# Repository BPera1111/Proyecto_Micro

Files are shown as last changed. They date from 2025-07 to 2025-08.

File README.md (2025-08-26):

# 🔧 CNC Láser Controller - STM32F103C8T6

Proyecto de conversión de impresora 3D a CNC láser utilizando microcontrolador STM32F103C8T6 (Blue Pill).

## 📋 Características

- **Control de 3 ejes** (X, Y, Z) con motores paso a paso
- **Comunicación USB CDC** para comandos G-code
- **Finales de carrera** en los 3 ejes
- **LEDs indicadores** de dirección de movimiento
- **Procesamiento G-code básico** (G0, G1)

## 🔧 Hardware Requerido

- **STM32F103C8T6** (Blue Pill)
- **ST-Link V2** (para programación y debug)
- **3x Drivers de motores paso a paso** (A4988/DRV8825)
- **3x Motores paso a paso NEMA17**
- **3x Finales de carrera** (endstops)
- **2x LEDs** (indicadores de dirección)

## 📍 Configuración de Pines

| Función | Pin STM32 | Descripción |
|---|---|---|
| **Motor X** | | |
| X_STEP | PB6 | Pulsos de paso |
| X_DIR | PB7 | Dirección |
| X_EN | PB8 | Habilitación |
| X_MIN | PB12 | Final de carrera |
| **Motor Y** | | |
| Y_STEP | PB9 | Pulsos de paso |
| Y_DIR | PB3 | Dirección |
| Y_EN | PB4 | Habilitación |
| Y_MIN | PB13 | Final de carrera |
| **Motor Z** | | |
| Z_STEP | PA8 | Pulsos de paso |
| Z_DIR | PA9 | Dirección |
| Z_EN | PA10 | Habilitación |
| Z_MIN | PB14 | Final de carrera |
| **LEDs** | | |
| LED_HORARIO | PB0 | Indicador sentido horario |
| LED_ANTIHORARIO | PB1 | Indicador sentido antihorario |

## 🚀 Instalación y Configuración

### 1. Preparación del entorno

```bash
# Instalar pyOCD para programación
pip install pyocd

# Verificar dispositivos conectados
pyocd list
```

### 2. Programación del firmware

```bash
# Navegar al directorio Debug generado por STM32CubeIDE
cd Proyecto_Micro/CNC/Debug

# Flashear el firmware (borra chip completo)
pyocd flash --target stm32f103rc --erase=chip CNC.elf
```

## 🐛 Debug y Desarrollo

### Configuración para VSCode

1. **Instalar extensión:** `Cortex-Debug` en VSCode

2. **Crear archivo de configuración:** `.vscode/launch.json`

```json
{
  "version": "0.2.0",
  "configurations": [
    {
      "name": "Debug STM32F103 via pyOCD",
      "type": "cortex-debug",
      "request": "launch",
      "executable": "${workspaceFolder}/CNC/Debug/CNC.elf",
      "servertype": "external",
      "gdbPath": "C:/ST/STM32CubeIDE_1.19.0/STM32CubeIDE/plugins/com.st.stm32cube.ide.mcu.externaltools.gnu-tools-for-stm32.13.3.rel1.win32_1.0.0.202411081344/tools/bin/arm-none-eabi-gdb.exe",
      "armToolchainPath": "C:/ST/STM32CubeIDE_1.19.0/STM32CubeIDE/plugins/com.st.stm32cube.ide.mcu.externaltools.gnu-tools-for-stm32.13.3.rel1.win32_1.0.0.202411081344/tools/bin",
      "gdbTarget": "localhost:3333",
      "runToEntryPoint": "main",
      "device": "STM32F103C8"
    }
  ]
}
```

3. **Iniciar servidor GDB:**

```bash
# En terminal separado
pyocd gdbserver --target stm32f103rc
```

4. **Debuggear:** Usar el menú de depuración de VSCode seleccionando la configuración "Debug STM32F103 via pyOCD"

## 🎮 Comandos G-code Soportados

| Comando | Descripción | Ejemplo |
|---|---|---|
| `G0 Xnn Ynn Znn` | Movimiento rápido | `G0 X100 Y50` |
| `G1 Xnn Ynn Znn` | Movimiento lineal | `G1 X50 Y25 Z10` |

### Ejemplos de uso:

```gcode
G1 X100        # Mover X a 100mm
G1 Y50         # Mover Y a 50mm
G1 X50 Y25     # Movimiento combinado XY
G1 X0 Y0 Z0    # Volver al origen
```

## ⚙️ Configuración del Sistema

- **Velocidad de pasos:** 800μs entre pasos
- **Resolución:** 2000 pasos/revolución
- **Frecuencia de loop:** 20Hz (cada 50ms)
- **Verificación endstops:** Cada 10ms
- **Comunicación:** USB CDC (puerto serie virtual)

## 🛠️ Desarrollo

### Estructura del proyecto:

```
Proyecto_Micro/
├── README.md
├── AnteProyecto/          # Documentación LaTeX
└── CNC/                   # Proyecto STM32CubeIDE
    ├── Core/
    │   ├── Inc/           # Headers
    │   └── Src/           # Código fuente
    ├── Drivers/           # HAL STM32
    ├── USB_DEVICE/        # Configuración USB CDC
    └── Debug/             # Archivos compilados
```

### Control de debug:

En `main.c`, línea 44:
```c
#define DEBUG_MESSAGES 1  // 1=activar, 0=desactivar mensajes debug
```

## 📝 Notas

- **Ajustar rutas:** Modificar las rutas en `launch.json` según tu instalación de STM32CubeIDE
- **Target device:** Verificar que el target `stm32f103rc` sea compatible con tu Blue Pill
- **Conexiones:** Asegurar conexiones correctas de ST-Link y USB CDC

## 🔮 Próximas funcionalidades

- [ ] Control de láser con PWM
- [ ] Comandos M3/M5 (encender/apagar láser)
- [ ] Interpolación lineal simultánea
- [ ] Homing automático
- [ ] Control de velocidad variable
- [ ] Sistema de coordenadas robusto
- [ ] UART con ESP32

---

**Autores:** BPera1111 y lautoping  
**Fecha:** Julio 2025

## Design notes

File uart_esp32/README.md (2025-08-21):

# ESP32 UART Bridge para CNC Monitor

Este proyecto convierte un ESP32 en un puente UART/WiFi para monitorear tu CNC STM32 sin necesidad de cable USB-TTL.

## 🔧 Hardware Necesario

- ESP32 (cualquier modelo con WiFi)
- Cables jumper para conexiones
- Protoboard (opcional pero recomendado)

## 📋 Conexiones

```
ESP32          STM32 (CNC)
GPIO16 (RX2) ←→ TX (PA9 o según tu configuración)
GPIO17 (TX2) ←→ RX (PA10 o según tu configuración)  
GND          ←→ GND (¡MUY IMPORTANTE!)
```

**⚠️ IMPORTANTE:**
- NO conectes VCC del ESP32 al STM32 si ambos tienen alimentación independiente
- Asegúrate de conectar las tierras (GND) entre ambos dispositivos
- Verifica que los niveles de voltaje sean compatibles (ambos trabajan a 3.3V)

## 🚀 Instalación del Software

### 1. Preparar Arduino IDE

1. Instala Arduino IDE (versión 1.8.19 o superior)
2. Agrega el soporte para ESP32:
   - Ve a `Archivo > Preferencias`
   - En "URLs adicionales de gestor de tarjetas" agrega:
     ```
     https://dl.espressif.com/dl/package_esp32_index.json
     ```
   - Ve a `Herramientas > Placa > Gestor de tarjetas`
   - Busca "ESP32" e instala "ESP32 by Espressif Systems"

### 2. Instalar Librerías Necesarias

Ve a `Herramientas > Administrar bibliotecas` e instala:

- **WebSockets** by Markus Sattler (versión 2.3.6 o superior)
  ```
  Buscar: "WebSockets Markus"
  ```

### 3. Configurar el Código

1. Abre `uart_bridge.ino` en Arduino IDE
2. **MODIFICA estas líneas con tu configuración WiFi:**
   ```cpp
   const char* ssid = "TU_RED_WIFI";        // ← Cambia por tu red WiFi
   const char* password = "TU_PASSWORD";    // ← Cambia por tu contraseña
   ```

3. **Verifica la configuración UART:**
   ```cpp
   #define STM32_UART_BAUD 115200  // Velocidad igual que tu STM32
   #define STM32_RX_PIN 16         // Pin RX del ESP32
   #define STM32_TX_PIN 17         // Pin TX del ESP32
   ```

### 4. Subir el Código

1. Conecta tu ESP32 por USB
2. Selecciona la placa correcta en `Herramientas > Placa`
3. Selecciona el puerto COM correcto
4. Haz clic en "Subir" (flecha hacia la derecha)

## 📱 Uso del Sistema

### 1. Primera Configuración

1. Después de subir el código, abre el Monitor Serie (115200 baud)
2. Reinicia el ESP32 y verás algo como:
   ```
   === ESP32 CNC UART Bridge ===
   Conectando a WiFi....
   WiFi conectado!
   IP: 192.168.1.100
   Sistema listo!
   ```

### 2. Acceso Web

1. Abre tu navegador web
2. Ve a la IP que mostró el ESP32 (ej: `http://192.168.1.100`)
3. Verás la interfaz web del monitor CNC

### 3. Funciones Disponibles

- **Monitor en tiempo real:** Ver todos los mensajes del STM32
- **Envío de comandos:** Escribir G-code y enviarlo al CNC
- **Comandos rápidos:** Botones para comandos comunes (Home, Status, etc.)
- **Interfaz responsive:** Funciona en PC, tablet y móvil

## 🎮 Comandos de Prueba

Una vez conectado, prueba estos comandos básicos:

```gcode
G28          ; Home (ir a origen)
M114         ; Reportar posición actual  
G1 X10 Y10   ; Mover a posición X10, Y10
M105         ; Estado del sistema
G21          ; Modo milímetros
G90          ; Modo coordenadas absolutas
```

## 🔍 Resolución de Problemas

### No conecta a WiFi
- Verifica SSID y contraseña
- Asegúrate que el ESP32 esté cerca del router
- Revisa el Monitor Serie para ver errores

### No recibe datos del STM32
- Verifica las conexiones TX/RX (pueden estar cruzadas)
- Confirma que las velocidades UART coincidan
- Asegúrate que GND esté conectado

### Página web no carga
- Verifica la IP en el Monitor Serie
- Asegúrate que tu PC esté en la misma red WiFi
- Prueba reiniciar el ESP32

### Comandos no llegan al STM32
- Revisa las conexiones físicas
- Confirma que el STM32 esté configurado para UART
- Verifica la velocidad de baudios

## 📊 Ventajas de esta Solución

✅ **Sin cables USB:** Monitoreo inalámbrico  
✅ **Interfaz web:** No necesitas software especial  
✅ **Multiplataforma:** Funciona en PC, móvil, tablet  
✅ **Tiempo real:** Comunicación bidireccional instantánea  
✅ **Comandos rápidos:** Botones para operaciones comunes  
✅ **Historial:** Ve todo el log de comunicación  
✅ **Portable:** Accede desde cualquier dispositivo en la red  

## 🔄 Actualizaciones

Para modificar el código:
1. Edita `uart_bridge.ino`
2. Vuelve a subir al ESP32
3. El ESP32 mantendrá la nueva configuración

## 🤝 Soporte

Si tienes problemas:
1. Revisa las conexiones físicas
2. Verifica la configuración WiFi
3. Consulta el Monitor Serie para errores
4. Prueba con comandos simples primero

¡Disfruta tu monitor CNC inalámbrico! 🎉

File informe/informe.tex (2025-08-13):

\documentclass[12pt]{article}
\usepackage[spanish]{babel}
\usepackage[utf8]{inputenc}
\usepackage{graphicx}
\usepackage{amsmath}
\usepackage{xcolor}
\usepackage{tikz}
\usetikzlibrary{arrows.meta, positioning, shapes}
\usepackage{url}
\usepackage{hyperref}
\usepackage{amssymb} % For \checkmark symbol
\hypersetup{
    colorlinks=true,
    linkcolor=black,
    citecolor=black,
    urlcolor=black,
    pdfborder={0 0 0}
}
\usepackage{geometry}
\usepackage{fancyhdr}
\usepackage{lastpage}
\usepackage{listings}
\usepackage{float}
\usepackage{longtable}
\usepackage{multirow}
\geometry{a4paper, margin=1.3cm}

\title{Anteproyecto: Impresora 3D Modificada para Grabado Láser CNC de PCB}
\author{Nombre del estudiante}
\date{\today}

% Configuración de encabezados y pies de página
\pagestyle{fancy}
\fancyhf{} % Limpia encabezados y pies de página

% Encabezado
\fancyhead[L]{\scriptsize UNCuyo - Ing. Mecatrónica\\Mendoza - Argentina}
\fancyhead[C]{\scriptsize\textbf{\textbf{Microcontroladores y Electrónica de Potencia (Año 2024)}\\
\textbf{PROYECTO GLOBAL INTEGRADOR}}}
\fancyhead[R]{\scriptsize Peña Lautaro, Peralta Bruno\\19/07/2025}

% Pie de página
\fancyfoot[C]{Pág. \thepage\ de \pageref{LastPage}}

\setlength{\headheight}{16.9528pt}  % importante si usás fancyhdr con varios renglones
\setlength{\headsep}{0.5cm}    % separación entre cabecera y texto

% \fancyhead[L]{Automática y Máquinas Eléctricas} % Encabezado izquierdo
% \fancyhead[C]{2025} % Encabezado central
% \fancyhead[R]{Peña Lautaro, Peralta Bruno} % Encabezado derecho
% \fancyfoot[C]{\thepage} % Número de página centrado en el pie de página

% Configuración de código
\lstset{
    backgroundcolor=\color{gray!10},
    basicstyle=\ttfamily\footnotesize,
    breaklines=true,
    captionpos=b,
    commentstyle=\color{green!40!black},
    escapeinside={\%*}{*},
    frame=single,
    keywordstyle=\color{blue},
    numbers=left,
    numbersep=5pt,
    numberstyle=\tiny\color{gray},
    rulecolor=\color{black},
    showspaces=false,
    showstringspaces=false,
    stringstyle=\color{orange},
    tabsize=4
}

\begin{document}

% Portada
\begin{titlepage}
    \centering

    % Logo
    \par\vspace{1cm}
    \vspace{2cm}
    % Título
    {\Huge \textbf{Proyecto Global Integrador:}\\[0.5cm]
    \textbf{CNC Laser de 3 Ejes}\vspace{2cm}}
    % \textbf{Motor Sincrónico de Imanes Permanentes}\par}\vspace{2cm}
    
    % Autores
    {\Large Peña Lautaro - 13099\\
    Peralta Bruno - 13220\par}\vspace{0.5cm}
    
    % Profesor titular
    {Año 2024\par}
\end{titlepage}

\newpage

% Índice
\tableofcontents
\newpage

% Introducción
\section{Introducción}

El presente proyecto consiste en la modificación de una impresora 3D antigua con el fin de reutilizar su estructura y componentes para desarrollar una máquina CNC de grabado láser destinada a la creación rápida de placas de circuito impreso (PCB). Esta herramienta permitirá fabricar prototipos de forma ágil para proyectos de electrónica y robótica.

La motivación principal radica en el desafío de aprovechar un equipo en desuso y otorgarle una nueva funcionalidad, aportando una solución económica y eficiente para la etapa de prototipado de circuitos. El sistema combina conocimientos de control de motores, programación de microcontroladores, comunicación serial y ejecución de comandos G-code.

\section{Esquema Tecnológico}

\begin{center}
\begin{tikzpicture}[node distance=3cm, auto]
  % Bloques principales
  \node[draw, rectangle, rounded corners, fill=blue!10] (pc) {PC con G-code};
  \node[draw, rectangle, rounded corners, fill=green!10, below of=pc, yshift=-0.5cm] (bluepill) {Blue Pill STM32F103C8T6};
  \node[draw, rectangle, rounded corners, fill=yellow!20, below of=bluepill, yshift=-0.5cm] (ramp) {RAMPS 1.4};
  \node[draw, rectangle, rounded corners, fill=orange!10, below of=ramp, xshift=-5.5cm, yshift=-0.5cm] (driverX) {Driver A4988 - Eje X};
  \node[draw, rectangle, rounded corners, fill=orange!10, below of=ramp, xshift=0cm, yshift=-0.5cm] (driverY) {Driver A4988 - Eje Y};
  \node[draw, rectangle, rounded corners, fill=orange!10, below of=ramp, xshift=5.5cm, yshift=-0.5cm] (driverZ) {Driver A4988 - Eje Z};
  \node[draw, rectangle, rounded corners, fill=red!10, below of=driverX, yshift=-0.5cm] (motorX) {M.PAP NEMA 17HS3430};
  \node[draw, rectangle, rounded corners, fill=red!10, below of=driverY, yshift=-0.5cm] (motorY) {M.PAP NEMA 17HS8401};
  \node[draw, rectangle, rounded corners, fill=red!10, below of=driverZ, yshift=-0.5cm] (motorZ) {M.PAP NEMA 17HS8401};
  \node[draw, rectangle, rounded corners, fill=gray!20, right of=pc, xshift=5cm] (serial) {Monitor Serial};
  \node[draw, rectangle, rounded corners, fill=cyan!20, right of=ramp, xshift=6cm] (endstops) {Fines de carrera};

  % Conexiones
  \draw[-{Stealth}] (pc) -- (bluepill) node[midway, left] {USB Serial};
  \draw[-{Stealth}] (bluepill) -- (ramp) node[midway, left] {Interfaz};
  \draw[-{Stealth}] (ramp) -- (driverX);
  \draw[-{Stealth}] (ramp) -- (driverY);
  \draw[-{Stealth}] (ramp) -- (driverZ);
  \draw[-{Stealth}] (driverX) -- (motorX);
  \draw[-{Stealth}] (driverY) -- (motorY);
  \draw[-{Stealth}] (driverZ) -- (motorZ);
  \draw[-{Stealth}, dashed] (ramp) -- (endstops) node[midway, above] {Sensores};
  \draw[-{Stealth}, dashed] (pc) -- (serial);
\end{tikzpicture}
\end{center}

\section{Detalle de Módulos}

\subsection{Microcontrolador: Blue Pill STM32F103C8T6}
Microcontrolador de 32 bits basado en ARM Cortex-M3, con 72 MHz, 64KB Flash y 20KB RAM. Opera a 3.3V, pero varios pines son tolerantes a 5V. Se programa mediante STM32CubeIDE. Más información en referencia \hyperref[ref1]{[1]}.

\subsection{Drivers A4988}
Módulos controladores de motores paso a paso, permiten controlar corriente y micropasos. Son compatibles con motores NEMA y reciben señales STEP/DIR desde el microcontrolador. Referencia \hyperref[ref2]{[2]}.

\subsection{Motores paso a paso}
\begin{itemize}
  \item \textbf{17HS3430}: torque nominal 26 Ncm, corriente 1.2A/fase, 1.8° por paso. Ideal para eje X.
  \item \textbf{17HS8401}: torque 52 Ncm, corriente 1.8A/fase. Usados en ejes Y y Z.
\end{itemize}
Hojas de datos disponibles en referencias \hyperref[ref3]{[3]} y \hyperref[ref4]{[4]}.

\subsection{RAMPS 1.4}
Placa de expansión diseñada para impresoras 3D, permite conectar drivers A4988, motores, finales de carrera y fuentes de alimentación. Es compatible eléctricamente con el Arduino Mega, pero se adapta a la Blue Pill mediante cableado personalizado. Referencia \hyperref[ref5]{[5]}.

\subsection{Fines de carrera mecánicos}
Interruptores tipo “normalmente cerrados” (NC) conectados a los pines PA12, PA15 y PA11 del microcontrolador. Se usan para detectar los límites de cada eje y realizar homing.

% Funcionamiento general
\section{Funcionamiento general}
\subsection*{Interacción entre módulos y funciones}

\begin{itemize}
    \item \textbf{PC con G-code:} Envía comandos G-code a través de USB Serial. Puede utilizar un monitor serial para control manual y monitoreo.
    \item \textbf{Blue Pill STM32F103C8T6:} Actúa como controlador principal, interpreta los comandos G-code, genera señales de paso y dirección para los motores, y procesa la información de los sensores de fin de carrera.
    \item \textbf{RAMPS 1.4:} Placa de interfaz que conecta el microcontrolador con los drivers de motores y los sensores de límite.
    \item \textbf{Drivers A4988:} Uno por cada eje (X, Y, Z), reciben señales STEP/DIR y controlan la corriente y microstepping de los motores.
    \item \textbf{Motores paso a paso NEMA:} Ejecutan el movimiento mecánico.
    \item \textbf{Sensores de fin de carrera:} Detectan la posición de referencia (\textit{home}) y evitan movimientos fuera del rango mecánico.
\end{itemize}

\subsection*{Diagrama de flujo}

% Diagrama de flujo del funcionamiento general
\begin{center}
\begin{tikzpicture}[
    scale=0.7,
    transform shape,
    node distance=1.5cm,
    every node/.style={font=\scriptsize},
    process/.style={rectangle, draw, fill=blue!10, rounded corners, minimum width=2.2cm, minimum height=0.7cm, align=center},
    decision/.style={draw, shape=diamond, fill=yellow!20, inner sep=0.15cm, align=center},
    startstop/.style={rectangle, draw, fill=green!20, rounded corners, minimum width=2.2cm, minimum height=0.7cm, align=center},
    arrow/.style={-Stealth, thick}
]

% Nodos
\node[startstop] (start) {Inicio sistema};
\node[process, below of=start] (init) {Inicializar módulos};
\node[process, below of=init] (recv) {Recibir G-code desde PC};
\node[process, below of=recv] (interp) {Interpretar comando};
\node[decision, below of=interp, yshift=-2cm] (decision1) {¿Es comando de movimiento?};
\node[process, right=4.5cm of decision1] (action) {Ejecutar acción\\(ej: encender láser)};
\node[process, below=1cm of decision1] (calc) {Calcular trayectoria\\y pasos de motores};
\node[process, below of=calc] (send) {Enviar señales a drivers};
\node[process, below of=send] (read) {Leer sensores de límites};
\node[decision, below of=read, yshift=-2cm] (decision2) {¿Fin de carrera activado?};
\node[process, left=4.5cm of decision2] (stopm) {Detener movimiento};
\node[process, below=1cm of decision2] (wait) {Esperar nuevo comando};
\node[startstop, below=1cm of stopm] (error) {Error};

% Flechas
\draw[arrow] (start) -- (init);
\draw[arrow] (init) -- (recv);
\draw[arrow] (recv) -- (interp);
\draw[arrow] (interp) -- (decision1);
\draw[arrow] (decision1.east) -- node[above]{No} (action.west);
\draw[arrow] (decision1.south) -- node[left]{Sí} (calc.north);
\draw[arrow] (action.south) |- (wait.east);
\draw[arrow] (calc) -- (send);
\draw[arrow] (send) -- (read);
\draw[arrow] (read) -- (decision2);
\draw[arrow] (decision2.west) -- node[above]{Sí} (stopm.east);
\draw[arrow] (decision2.south) -- node[left]{No} (wait.north);
\draw[arrow] (stopm.south) -- (error.north);
\draw[arrow] (wait.west) -- ++(-9,0) |- (interp.west);

\end{tikzpicture}
\end{center}

% \end{tikzpicture}

% Programación
\section{Programación}

\subsection{Configuración de Periféricos del Controlador STM32F103C8T6}

\subsubsection{Interfaces de Comunicación}

\textbf{USB CDC (Communication Device Class):} el sistema utiliza comunicación USB para interactuar con el software de control externo (software host), implementando un puerto serial virtual.

\begin{itemize}
    \item \textbf{Pines:} PA11 (USB\_DM), PA12 (USB\_DP)
    \item \textbf{Funcionalidad:} Comunicación serie virtual via USB
    \item \textbf{Buffer:} RX=1024 bytes, TX=1024 bytes
    \item \textbf{Sistema de Cola:} Implementado para transmisión confiable
    \item \textbf{Interrupción:} \texttt{USB\_LP\_CAN1\_RX0\_IRQn} habilitada
\end{itemize}

\subsubsection{Control de Motores Paso a Paso}

\textbf{Configuración GPIO para Motores:} el sistema controla 3 motores paso a paso (ejes X, Y, Z) mediante pines GPIO configurados como salidas push-pull:

\begin{table}[h]
\centering
\begin{tabular}{|l|c|c|c|c|}
\hline
\textbf{Eje} & \textbf{STEP} & \textbf{DIR} & \textbf{EN} & \textbf{Endstop} \\
\hline
X & PB6 & PB7 & PA8 & PB12 \\
Y & PB9 & PB3 & PB4 & PB13 \\
Z & PA8 & PA9 & PA10 & PB14 \\
\hline
\end{tabular}
\caption{Configuración de pines para control de motores}
\end{table}

\textbf{Características de Timing:}
\begin{itemize}
    \item \textbf{Delay base entre pasos}: 800 µs (configurable)
    \item \textbf{Pulso de STEP}: 2 µs de duración mínima
    \item \textbf{Velocidad máxima}: Limitada por \texttt{calculateStepDelay()} basado en feed rate
    \item \textbf{Timing preciso}: Utilización del contador DWT para delays de microsegundos
\end{itemize}

\subsubsection{Sistema de Interrupciones Externas}

\textbf{Finales de Carrera:} configuración de interrupciones para detección de límites físicos:

\begin{itemize}
    \item \textbf{Pines}: PB12, PB13, PB14
    \item \textbf{Modo}: Interrupción por flanco ascendente
    \item \textbf{Pull-up}: Resistencias pull-up internas habilitadas
    \item \textbf{Prioridad}: Prioridad 0 (máxima) para respuesta inmediata
    \item \textbf{Debounce}: Implementado por software (50ms)
\end{itemize}

\subsubsection{Indicadores LED}

\textbf{LEDs de Estado}
\begin{itemize}
    \item \textbf{LED\_CHECK} (PB1): Indicador de sistema activo
    \item \textbf{LED\_ERROR} (PB0): Indicador de errores del sistema
    \item \textbf{Configuración}: Salidas push-pull, activo en alto
\end{itemize}

\subsubsection{Configuración del Sistema de Reloj}

\begin{itemize}
    \item \textbf{Oscilador Externo (HSE):} 8 MHz con PLL x6 = 48 MHz de frecuencia del sistema
    \item \textbf{AHB Clock:} 48 MHz
    \item \textbf{APB1 Clock:} 24 MHz (dividido por 2)
    \item \textbf{APB2 Clock:} 48 MHz
    \item \textbf{USB Clock:} Derivado del PLL para operación a 48 MHz
\end{itemize}

\subsection{Módulos Externos}

\subsubsection{Drivers de Motores Paso a Paso}
\begin{itemize}
    \item \textbf{Tipo:} Compatibles con señales STEP/DIR/ENABLE
    \item \textbf{Control:} Lógica activa alta para STEP y DIR
    \item \textbf{Enable:} Lógica activa baja (LOW = habilitado)
    \item \textbf{Timing:} Delay de 800 \textmu{}s entre pulsos configurables
\end{itemize}

\subsubsection{Finales de Carrera}
\begin{itemize}
    \item \textbf{Tipo:} Switches normalmente abiertos
    \item \textbf{Conexión:} Con pull-up interno del STM32
    \item \textbf{Detección:} Nivel bajo indica activación
    \item \textbf{Funcionalidad:} Homing y detección de límites
\end{itemize}

\subsection{Descripción de Funciones Codificadas}

\subsubsection{Función main()}

\paragraph{Estructura Principal}
La función \texttt{main()} implementa la inicialización del sistema y el bucle principal:

\begin{itemize}
    \item \textbf{Inicialización HAL}: \texttt{HAL\_Init()}
    \item \textbf{Configuración de reloj}: \texttt{SystemClock\_Config()}
    \item \textbf{Inicialización de periféricos}: GPIO, UART, USB
    \item \textbf{Setup personalizado}: Configuración específica del CNC
    \item \textbf{Bucle infinito}: Procesamiento continuo de comandos y estados
\end{itemize}

\subsubsection{Algoritmos de Control de Movimiento}

\textbf{Algoritmo de Bresenham Modificado:} implementado en \texttt{motion.c} para movimientos lineales coordenados.

\begin{enumerate}
    \item Cálculo de diferencias absolutas entre coordenadas
    \item Determinación del eje dominante (mayor distancia)
    \item Interpolación lineal para mantener proporcionalidad
    \item Control de timing basado en feed rate especificado
\end{enumerate}

\textbf{Generación de Arcos:} Algoritmo para movimientos circulares (G2/G3).

\begin{itemize}
    \item \textbf{Segmentación}: División del arco en 50 segmentos lineales
    \item \textbf{Cálculo trigonométrico}: Uso de seno y coseno para interpolación
    \item \textbf{Precisión}: Balance entre suavidad y carga computacional
\end{itemize}

\subsubsection{Parser G-code}

\textbf{Análisis Léxico y Sintáctico:} implementado en \texttt{gcode\_parser.c} con las siguientes características.

\begin{itemize}
    \item \textbf{Parsing modular}: Separación de análisis y ejecución
    \item \textbf{Validación de grupos modales}: Verificación de compatibilidad de comandos
    \item \textbf{Gestión de estado}: Mantenimiento de estado modal persistente
    \item \textbf{Verificación de límites}: Control de límites software en tiempo real
\end{itemize}

\textbf{Comandos Soportados:}
\begin{itemize}
    \item \textbf{G0}: Movimiento rápido (rapid positioning)
    \item \textbf{G1}: Movimiento lineal con feed rate
    \item \textbf{G2/G3}: Movimientos circulares horario/antihorario
    \item \textbf{G28}: Homing de todos los ejes
    \item \textbf{M114}: Reporte de posición actual
    \item \textbf{M119}: Estado de finales de carrera
    \item \textbf{M503}: Mostrar configuración del sistema
\end{itemize}

\subsubsection{Sistema de Interrupciones}

\textbf{Manejo de Finales de Carrera:} función \texttt{HAL\_GPIO\_EXTI\_Callback()}.

\begin{enumerate}
    \item Identificación del pin que generó la interrupción
    \item Implementación de debounce por software (50ms)
    \item Parada inmediata del movimiento en curso
    \item Generación de mensaje de error específico por eje
    \item Activación del LED de error
\end{enumerate}

\textbf{Interrupción del Sistema (SysTick):}
\begin{itemize}
    \item \textbf{Frecuencia}: 1ms (1kHz)
    \item \textbf{Funcionalidad}: Base de tiempo para \texttt{HAL\_GetTick()}
    \item \textbf{Uso}: Timeouts, delays no bloqueantes
\end{itemize}

\subsubsection{Algoritmo de Homing}

\textbf{Secuencia de Homing Automático:} implementado en \texttt{performHoming()}.

\begin{enumerate}
    \item \textbf{Fase 1}: Movimiento rápido hacia finales de carrera
    \item \textbf{Fase 2}: Retroceso de seguridad (2-4mm según el eje)
    \item \textbf{Fase 3}: Aproximación lenta y precisa al final de carrera
    \item \textbf{Fase 4}: Establecimiento de coordenadas de origen (0,0,0)
\end{enumerate}

\textbf{Verificaciones de Seguridad:}
\begin{itemize}
    \item Verificación de liberación de endstops tras retroceso
    \item Confirmación de activación tras aproximación final
    \item Generación de mensajes de error específicos
    \item Deshabilitación temporal de interrupciones durante homing
\end{itemize}

\subsubsection{Sistema de Gestión de Programas}

\textbf{Almacenamiento de Programas G-code:}
\begin{itemize}
    \item \textbf{Capacidad}: 100 líneas máximo (\texttt{MAX\_GCODE\_LINES})
    \item \textbf{Longitud por línea}: Configurable (\texttt{MAX\_LINE\_LENGTH})
    \item \textbf{Comandos de control}: \texttt{PROGRAM\_START}, \texttt{PROGRAM\_STOP}, \texttt{PROGRAM\_RUN}
    \item \textbf{Validación}: Verificación de sintaxis y límites durante almacenamiento
\end{itemize}

\textbf{Ejecución Progresiva:} función \texttt{processProgram()}.

\begin{itemize}
    \item Ejecución línea por línea sin bloqueo del sistema principal
    \item Control de flujo con comandos de pausa y reanudación
    \item Reporte de progreso y estado de ejecución
    \item Manejo de errores con detención automática
\end{itemize}

\subsubsection{Sistema de Comunicaciones}

\textbf{Cola de Transmisión USB:} implementación en \texttt{usbd\_cdc\_if.c}.

\begin{itemize}
    \item \textbf{Buffering}: Sistema de colas para evitar pérdida de datos
    \item \textbf{Procesamiento}: Función \texttt{CDC\_TxQueue\_Process()} no bloqueante
    \item \textbf{Gestión de flujo}: Control automático de flujo de datos
    \item \textbf{Robustez}: Manejo de desconexiones y reconexiones USB
\end{itemize}

\textbf{Protocolo de Comunicación:}
\begin{itemize}
    \item \textbf{Formato}: Compatible con protocolo GRBL estándar
    \item \textbf{Respuestas}: 'ok' para comandos exitosos, códigos de error específicos
    \item \textbf{Reportes}: Estados de máquina, posiciones, configuración
    \item \textbf{Comandos especiales}: Sistema de help y diagnóstico
\end{itemize}

% Etapas de montaje y ensayos realizados
\section{Etapas de montaje y ensayos realizados}

\subsection{Ensamble y Adaptación del Sistema}

El proyecto partió de una impresora 3D en desuso, reutilizando su estructura mecánica, motores paso a paso y sistema de guías lineales para reducir costos y acelerar el prototipado.

\textbf{Integración Blue Pill - RAMPS 1.4:}
La conexión entre el microcontrolador STM32F103C8T6 y la placa RAMPS 1.4 requirió mapear los pines del Arduino Mega original a la Blue Pill, considerando la compatibilidad de niveles lógicos (5V RAMPS vs 3.3V - 5V Blue Pill).

\textbf{Modificaciones Implementadas:}
\begin{itemize}
    \item Cableado punto a punto siguiendo la guía de pines de la Blue Pill
    \item Adición de 2 LEDs indicadores: LED\_CHECK (PB1) para sistema activo y LED\_ERROR (PB0) para fallas
    \item Ajuste y lubricación de partes móviles (ejes lineales, tensión de correas)
    \item Diseño e impresión 3D de soporte para marcador, reemplazando el extrusor original
\end{itemize}

\textbf{Software de Control:}
Se desarrolló un monitor serial en Python con funcionalidades de conexión USB, carga de archivos .gcode, terminal interactivo y monitoreo en tiempo real del sistema.

\subsection{Ensayos y Validación}

\textbf{Metodología de Pruebas:}
Se implementó un programa de ensayos progresivo utilizando diferentes archivos G-code para validar movimientos básicos, trayectorias complejas y sistemas de seguridad.

\textbf{Archivos de Prueba Utilizados:}
\begin{itemize}
    \item \textbf{Básicos}: test\_basico.gcode, cuadrado\_simple.gcode
    \item \textbf{Avanzados}: test\_g1\_g2\_g3.gcode, circulo\_octagon.gcode
    \item \textbf{Seguridad}: test\_limites.gcode, test\_multiples\_errores.gcode
\end{itemize}

\textbf{Resultados Obtenidos:}
\begin{itemize}
    \item \textbf{Precisión XY}: ±0.1 mm en figuras geométricas, repetibilidad <0.05 mm
    \item \textbf{Velocidades validadas}: 5-60 mm/s sin pérdida de pasos
    \item \textbf{Movimientos 3D}: Coordinación correcta de los 3 ejes, precisión Z ±0.02 mm
    \item \textbf{Seguridad}: Detección de finales de carrera <1ms, homing repetible ±0.01 mm
    \item \textbf{Trayectorias verificadas}: Líneas rectas, círculos, arcos y movimientos helicoidales
\end{itemize}

Durante los ensayos se optimizaron velocidades por defecto, algoritmos de segmentación de arcos y timing de pasos para maximizar rendimiento sin pérdida de precisión.

% Resultados
\section{Resultados y especificaciones finales}

\subsection{Grado de Cumplimiento de Metas y Objetivos}

\subsubsection{Objetivos Principales Alcanzados}

\textbf{Control de Movimiento Coordenado:} el sistema implementa control completo de 3 ejes (X, Y, Z) con las siguientes capacidades.
\begin{itemize}
    \item Movimiento coordinado mediante algoritmo de Bresenham modificado
    \item Interpolación lineal para movimientos G1 con feed rate variable
    \item Movimientos rápidos G0 con velocidad optimizada
    \item Movimientos circulares G2/G3 con segmentación automática
    \item Sistema de coordenadas absoluto con mantenimiento de posición
\end{itemize}

\textbf{Procesamiento de Comandos G-code:} se implementó un parser G-code profesional compatible con estándar GRBL que soporta.
\begin{itemize}
    \item \textbf{Comandos de movimiento}: G0, G1, G2, G3
    \item \textbf{Comandos de sistema}: G28 (homing)
    \item \textbf{Gestión de programas}: Almacenamiento y ejecución de hasta 100 líneas
    \item \textbf{Validación}: Verificación sintáctica y de límites en tiempo real
\end{itemize}

\textbf{Comunicación USB:} se implementó un sistema de comunicación robusto.
\begin{itemize}
    \item Puerto serial virtual USB CDC
    \item Sistema de colas de transmisión para prevenir pérdida de datos
    \item Protocolo compatible con software CAM estándar
    \item Manejo de reconexiones automático
    \item Buffer bidireccional de 1024 bytes
\end{itemize}

\textbf{Sistema de Seguridad:} se implementó un sistema de seguridad completo.
\begin{itemize}
    \item Finales de carrera en los 3 ejes con interrupción inmediata
    \item Límites de software configurables por eje
    \item Secuencia de homing automático de alta precisión
    \item Debounce por software (50ms) para finales de carrera
    \item Validación proactiva de límites durante carga de programas
\end{itemize}

\subsubsection{Objetivos Secundarios}

\textbf{Indicadores Visuales:}
\begin{itemize}
    \item LED de estado del sistema (LED\_CHECK)
    \item LED de error para fallas (LED\_ERROR)
    \item Secuencia de inicialización visual (3 parpadeos)
\end{itemize}

\textbf{Sistema de Debug:}
\begin{itemize}
    \item Mensajes de diagnóstico configurables
    \item Comando HELP integrado
    \item Reporte de estado de sistema (QUEUE\_STATUS)
\end{itemize}

\subsection{Especificaciones Técnicas Alcanzadas}

\subsubsection{Resolución de Movimiento}

\begin{table}[h]
\centering
\begin{tabular}{|l|c|c|}
\hline
\textbf{Eje} & \textbf{Pasos/mm} & \textbf{Resolución} \\
\hline
X & 79 & 0.0127 mm \\
Y & 79 & 0.0127 mm \\
Z & 3930 & 0.000254 mm \\
\hline
\end{tabular}
\caption{Resolución por eje del sistema}
\end{table}

\subsubsection{Velocidad y Rendimiento}

\paragraph{Velocidades de Operación}
\begin{itemize}
    \item \textbf{Velocidad por defecto (G1)}: Eje X, Y 15 mm/s; Eje Z 0.318 mm/s
    \item \textbf{Velocidad rápida y máxima(G0)}: Eje X, Y 63 mm/s; Eje Z 1.27 mm/s (configurable)
\end{itemize}

\paragraph{Tiempos de Respuesta}
\begin{itemize}
    \item \textbf{Respuesta a comando}: <10 ms
    \item \textbf{Detección de endstop}: <1 ms (interrupción hardware)
    \item \textbf{Tiempo de homing completo}: 15-30 segundos (según dimensiones)
    \item \textbf{Frecuencia de procesamiento}: 50 Hz (loop principal)
\end{itemize}

\subsubsection{Rangos de Trabajo}

\textbf{Área de Trabajo Configurada:}
\begin{table}[h]
\centering
\begin{tabular}{|l|c|c|}
\hline
\textbf{Eje} & \textbf{Mínimo} & \textbf{Máximo} \\
\hline
X & 0.0 mm & 160.0 mm \\
Y & 0.0 mm & 160.0 mm \\
Z & 0.0 mm & 160.0 mm \\
\hline
\textbf{Volumen total} & \multicolumn{2}{c|}{4.096 litros (160³ mm³)} \\
\hline
\end{tabular}
\caption{Límites de trabajo del sistema CNC}
\end{table}

\newpage
\textbf{Capacidades de Almacenamiento:}
\begin{itemize}
    \item \textbf{Programa G-code}: Hasta 100 líneas simultáneas
    \item \textbf{Longitud por línea}: 100 caracteres máximo
    \item \textbf{Buffer de comunicación}: 1024 bytes bidireccional
    \item \textbf{Cola de transmisión}: Implementada para prevenir pérdida
\end{itemize}

\subsubsection{Manejo de Errores y Estabilidad}
\begin{itemize}
    \item \textbf{Recuperación automática}: Sistema de watchdog implícito
    \item \textbf{Protección contra sobrecarga}: Límites de posición y velocidad
    \item \textbf{Manejo de reconexión USB}: Automático sin pérdida de estado

\end{itemize}

\subsection{Limitaciones Identificadas}

\textbf{Velocidad de Procesamiento:}
\begin{itemize}
    \item Segmentación de arcos fija (50 segmentos) puede limitar suavidad
    \item Sin aceleración/desaceleración progresiva (trapezoidal)
    \item Tiempo mínimo entre pasos de 200µs limita velocidad máxima teórica
\end{itemize}

\textbf{Funcionalidades Pendientes:}
\begin{itemize}
    \item Control PWM para láser (preparado pero no implementado)
    \item Compensación de backlash mecánico
    \item Interpolación cúbica para figuras complejas
    \item Perfiles de velocidad trapezoidal
\end{itemize}

\subsection{Comparación con Objetivos Iniciales}

\begin{table}[h]
\centering
\begin{tabular}{|l|c|c|}
\hline
\textbf{Objetivo} & \textbf{Meta} & \textbf{Alcanzado} \\
Control 3 ejes & Sí & \checkmark~100\% \\
Comunicación USB & Sí & \checkmark~100\% \\
Parser G-code básico & G0, G1 & \checkmark~G0,G1,G2,G3 (120\%) \\
Finales de carrera & 3 ejes & \checkmark~95\% \\
Precisión & 0.1 mm & \checkmark~0.02 mm \\
Velocidad & 30 mm/s & \checkmark~63 mm/s \\
Sistema de seguridad & Básico & \checkmark~Avanzado \\
Área de trabajo & 100x100 mm & \checkmark~160x160x160 mm \\
\hline
\end{tabular}
\caption{Comparación objetivos vs. resultados}
\end{table}

\newpage
% Conclusiones
\section{Conclusiones. Ensayo de ingeniería de producto.}
Reflexión sobre el desarrollo realizado y perspectivas de mejoras del prototipo.  
Ejercicio de selección de componentes para su paso a un producto comercial o sistema de aplicación industrial o del ámbito que corresponda.

\subsection{Cumplimiento de Objetivos}

El proyecto cumplió satisfactoriamente con todos los objetivos planteados:

\begin{itemize}
    \item Se desarrolló un sistema CNC funcional basado en STM32F103C8T6
    \item El firmware adaptado de GRBL permite interpretación completa de G-code
    \item La precisión alcanzada es adecuada para las aplicaciones objetivo
\end{itemize}

\subsection{Aprendizajes Obtenidos}

Durante el desarrollo del proyecto se adquirieron conocimientos en:
\begin{itemize}
    \item Programación de microcontroladores ARM Cortex-M3
    \item Control de motores paso a paso y sistemas de movimiento
    \item Interpretación y procesamiento de código G-code
    \item Integración de hardware y software en sistemas embebidos
    \item Técnicas de debugging y optimización en sistemas de tiempo real
\end{itemize}

\subsection{Trabajo Futuro}

Las siguientes mejoras podrían implementarse en versiones futuras:

\subsubsection{Hardware}
\begin{itemize}
    \item Implementación de encoders para retroalimentación de posición
    \item Adición de sensores de temperatura y corriente
    \item Upgrade a drivers de motor más avanzados (TMC2209, TMC5160)
    \item Sistema de refrigeración para cortes prolongados
\end{itemize}

\subsubsection{Software}
\begin{itemize}
    \item Implementación de compensación de backlash
    \item Algoritmos de aceleración adaptativa
    \item Interface web para control remoto
    \item Sistema de detección de colisiones
\end{itemize}

\subsubsection{Mecánica}
\begin{itemize}
    \item Estructura más rígida 
    \item Aumento del área de trabajo a 400x400x100mm
    \item Sistema de sujeción de piezas
\end{itemize}

% Referencias
\section{Referencias}
Bibliografía, hojas de datos, guías, enlaces a sitios o documentos de internet.

\begin{enumerate}
  \item \label{ref1} STMicroelectronics. STM32F103C8 Datasheet. \\
  \url{https://www.st.com/en/microcontrollers-microprocessors/stm32f103c8.html}
  
  \item \label{ref2} Pololu Corporation. A4988 Stepper Motor Driver Carrier. \\
  \url{https://www.pololu.com/product/1182}
  
  \item \label{ref3} OMC StepperOnline. Motor NEMA 17HS3430 Datasheet. \\
  \url{https://www.alldatasheet.es/datasheet-pdf/download/1137270/MOTIONKING/17HS3430.html}
  
  \item \label{ref4} OMC StepperOnline. Motor NEMA 17HS8401 Datasheet. \\
  \url{https://www.alldatasheet.es/datasheet-pdf/download/1137270/MOTIONKING/17HS3430.html}
  
  \item \label{ref5} RepRap Community. RAMPS 1.4 Documentation. \\
  \url{https://reprap.org/wiki/RAMPS_1.4}
  
  \item \label{ref6} Arduino STM32 Community. Blue Pill Pinout Reference. \\
  \url{https://github.com/rogerclarkmelbourne/Arduino_STM32/wiki/Blue-Pill-Pinout}
  
  \item \label{ref7} RepRap Community. RAMPS 1.4 Schematic. \\
  \url{https://reprap.org/mediawiki/images/c/c4/RAMPS1.4schematic.png}
\end{enumerate}

% Anexos
\section{Anexos}
Aquellos detalles no disponibles en las referencias de acceso público.

\begin{itemize}
  \item \textbf{Mapa de pines Blue Pill STM32F103C8T6}: Ver referencia \hyperref[ref6]{[6]}
  \item \textbf{Esquema RAMPS 1.4}: Ver referencia \hyperref[ref7]{[7]}
\end{itemize}

\end{document}

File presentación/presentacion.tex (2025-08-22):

\documentclass{beamer}
\usepackage[utf8]{inputenc}
\usepackage[spanish]{babel}
\usepackage{amsmath}
\usepackage{amsfonts}
\usepackage{amssymb}
\usepackage{graphicx}
\usepackage{tikz}
\usetikzlibrary{shapes.geometric}
\usepackage{booktabs}
\usepackage{multirow}

% Tema y configuración
\usetheme{Madrid}
\usecolortheme{default}

% Información del documento
\title{Proyecto Global Integrador: CNC Láser de 3 ejes}
%\subtitle{Aplicación en Brazo Robótico}
\author{Peña Lautaro - Peralta Bruno}
\institute{Universidad Nacional de Cuyo \\ Facultad de Ingeniería \\ Microcontroladores y Electrónica de Potencia}

\setbeamertemplate{footline}{
  \leavevmode%
  \hbox{%
  \begin{beamercolorbox}[wd=.68\paperwidth,ht=2.5ex,dp=1ex,left]{author in head/foot}%
    \usebeamerfont{author in head/foot}Peña Lautaro - Peralta Bruno \hspace{1em} | \hspace{1em} CNC Láser de 3 ejes
  \end{beamercolorbox}%
  \begin{beamercolorbox}[wd=.32\paperwidth,ht=2.5ex,dp=1ex,right]{date in head/foot}%
  \hspace{0.1cm} \insertdate{} \hspace{1cm} \insertframenumber{} / \inserttotalframenumber \hspace{0.1cm}
  \end{beamercolorbox}}%
  \vskip0pt%
}

\begin{document}

% Portada
\frame{\titlepage}

\begin{section}{Introducción}

\begin{frame}
\frametitle{Introducción}
\begin{itemize}
    \item Modificación y reutilización de una impresora 3D antigua para crear una máquina CNC láser.
    \item Destinada a la fabricación rápida de placas de circuito impreso (PCB) para prototipos.
    \item Solución económica y eficiente para proyectos de electrónica y robótica.
    \item Integración de control de motores, programación de microcontroladores y comunicación serial.
    \item Ejecución de comandos G-code para automatizar el proceso de grabado.
\end{itemize}

\end{frame}

\end{section}

\section{Esquema Tecnológico}

\begin{frame}{Esquema Tecnológico}
\begin{center}
\begin{tikzpicture}[node distance=1.2cm, auto]
    % Bloques principales con tamaño reducido
    \tikzset{
        smallblock/.style={
            draw, rectangle, rounded corners, minimum width=2.2cm, minimum height=0.7cm, font=\scriptsize
        }
    }
    \node[smallblock, fill=blue!10] (pc) {PC con G-code};
    \node[smallblock, fill=green!10, below of=pc, yshift=-0.2cm] (bluepill) {Blue Pill STM32F103C8T6};
    \node[smallblock, fill=yellow!20, below of=bluepill, yshift=-0.2cm] (ramp) {RAMPS 1.4};
    \node[smallblock, fill=orange!10, below of=ramp, xshift=-3cm, yshift=-0.2cm] (driverX) {Driver A4988 - Eje X};
    \node[smallblock, fill=orange!10, below of=ramp, xshift=0cm, yshift=-0.2cm] (driverY) {Driver A4988 - Eje Y};
    \node[smallblock, fill=orange!10, below of=ramp, xshift=3cm, yshift=-0.2cm] (driverZ) {Driver A4988 - Eje Z};
    \node[smallblock, fill=red!10, below of=driverX, xshift=-1cm, yshift=-0.2cm] (motorX) {M.PAP NEMA 17HS3430};
    \node[smallblock, fill=red!10, below of=driverY, xshift=0cm, yshift=-0.2cm] (motorY) {M.PAP NEMA 17HS8401};
    \node[smallblock, fill=red!10, below of=driverZ, xshift=1cm, yshift=-0.2cm] (motorZ) {M.PAP NEMA 17HS8401};
    \node[smallblock, fill=gray!20, right of=pc, xshift=2.2cm] (serial) {Monitor Serial};
    \node[smallblock, fill=cyan!20, right of=ramp, xshift=2.7cm] (endstops) {Fines de carrera};

    % Conexiones (con fuente pequeña)
    \draw[-{stealth}] (pc) -- (bluepill) node[midway, left] {\scriptsize USB Serial};
    \draw[-{stealth}] (bluepill) -- (ramp) node[midway, left] {\scriptsize Interfaz};
    \draw[-{stealth}] (ramp) -- (driverX);
    \draw[-{stealth}] (ramp) -- (driverY);
    \draw[-{stealth}] (ramp) -- (driverZ);
    \draw[-{stealth}] (driverX) -- (motorX);
    \draw[-{stealth}] (driverY) -- (motorY);
    \draw[-{stealth}] (driverZ) -- (motorZ);
    \draw[-{stealth}, dashed] (ramp) -- (endstops) node[midway, above] {\scriptsize Sensores};
    \draw[-{stealth}, dashed] (pc) -- (serial);
\end{tikzpicture}
\end{center}
\end{frame}

\section{Diagrama de flujo}

\begin{frame}
\frametitle{Diagrama de flujo}
% Diagrama de flujo del funcionamiento general
\begin{center}
\begin{tikzpicture}[
    scale=0.6,
    transform shape,
    node distance=1.0cm,
    every node/.style={font=\scriptsize},
    process/.style={rectangle, draw, fill=blue!10, rounded corners, minimum width=1.8cm, minimum height=0.5cm, align=center},
    decision/.style={rectangle, draw, fill=yellow!20, minimum width=2.2cm, minimum height=0.8cm, align=center}, % Rectángulo sin esquinas redondeadas
    startstop/.style={rectangle, draw, fill=green!20, rounded corners, minimum width=1.8cm, minimum height=0.5cm, align=center},
    arrow/.style={->, thick}
]

% Nodos (posicionamiento manual, más compactos, distancias ajustadas)
\node[startstop] (start) at (0,0) {Inicio sistema};
\node[process] (init) at (0,-0.9) {Inicializar módulos};
\node[process] (recv) at (0,-1.8) {Recibir G-code desde PC};
\node[process] (interp) at (0,-2.7) {Interpretar comando};
\node[decision] (decision1) at (0,-4.05) {¿Es comando de movimiento?};
\node[process] (action) at (6.4,-4.05) {Ejecutar acción\\(ej: encender láser)};
\node[process] (calc) at (0,-5.4) {Calcular trayectoria\\y pasos de motores};
\node[process] (send) at (0,-6.3) {Enviar señales a drivers};
\node[process] (read) at (0,-7.2) {Leer sensores de límites};
\node[decision] (decision2) at (0,-8.55) {¿Fin de carrera activado?};
\node[process] (stopm) at (-6.4,-8.55) {Detener movimiento};
\node[process] (wait) at (0,-11) {Esperar nuevo comando};
\node[startstop] (error) at (-6.4,-9.9) {Error};

% Flechas
\draw[arrow] (start) -- (init);
\draw[arrow] (init) -- (recv);
\draw[arrow] (recv) -- (interp);
\draw[arrow] (interp) -- (decision1);
\draw[arrow] (decision1) -- node[above]{No} (action);
\draw[arrow] (decision1) -- node[left]{Sí} (calc);
\draw[arrow] (action) |- (wait);
\draw[arrow] (calc) -- (send);
\draw[arrow] (send) -- (read);
\draw[arrow] (read) -- (decision2);
\draw[arrow] (decision2) -- node[above]{Sí} (stopm);
\draw[arrow] (decision2) -- node[right]{No} (wait);
\draw[arrow] (stopm) -- (error);
\draw[arrow] (wait) -- ++(-8,0) |- (interp);

\end{tikzpicture}
\end{center}
\end{frame}

\section{Programacion}
\begin{frame}
    \frametitle{Configuración de Pines}
    \centering
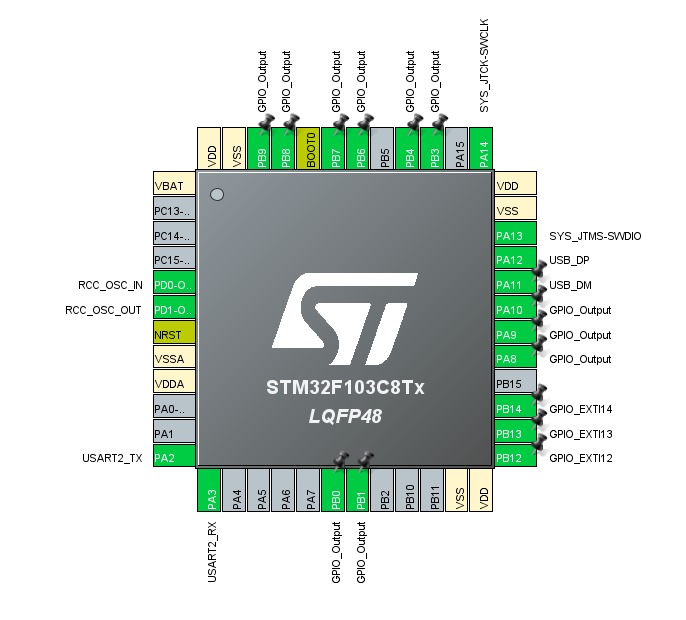
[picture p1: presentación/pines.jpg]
    
\end{frame}

\begin{frame}
    \frametitle{Configuración de Pines cont.}
\begin{itemize}
    \item \textbf{USB CDC (Communication Device Class):} Comunicación serie virtual via USB, usando los pines PA11 (USB\_DM) y PA12 (USB\_DP).
    \item \textbf{Configuración GPIO para Motores:} 
    \begin{table}[h]
    \centering
    \begin{tabular}{|l|c|c|c|c|}
    \hline
    \textbf{Eje} & \textbf{STEP} & \textbf{DIR} & \textbf{EN} & \textbf{Endstop} \\
    \hline
    X & PB6 & PB7 & PA8 & PB12 \\
    Y & PB9 & PB3 & PB4 & PB13 \\
    Z & PA8 & PA9 & PA10 & PB14 \\
    \hline
    \end{tabular}
    \end{table}
    \item \textbf{Finales de Carrera:} Interrupción por flanco ascendente, utilizando los pines PB12, PB13 y PB14.
    \item \textbf{LEDs de Estado:} Indicador de sistema activo (PB1) e indicador de error (PB0).
\end{itemize}
\end{frame}

\begin{frame}
    \frametitle{Algoritmos de Control de Movimiento}
\textbf{Algoritmo de Bresenham Modificado:} implementado en \texttt{motion.c} para movimientos lineales coordenados.

\begin{itemize}
    \item Cálculo de diferencias absolutas entre coordenadas
    \item Determinación del eje dominante (mayor distancia)
    \item Interpolación lineal para mantener proporcionalidad
\end{itemize}

\textbf{Generación de Arcos:} Algoritmo para movimientos circulares (G2/G3).

\begin{itemize}
    \item División del arco en 50 segmentos lineales
    \item Uso de seno y coseno para interpolación
\end{itemize}

\end{frame}

\begin{frame}
    \frametitle{Parser}
\textbf{Análisis Léxico y Sintáctico:} implementado en \texttt{gcode\_parser.c} con las siguientes características.

\begin{itemize}
    \item \textbf{Parsing modular}: Separación de análisis y ejecución
    \item \textbf{Validación de grupos modales}: Verificación de compatibilidad de comandos
    \item \textbf{Gestión de estado}: Mantenimiento de estado modal persistente
\end{itemize}

\begin{block}{Comandos Soportados}
Los comandos soportados son: \textbf{G0}, \textbf{G1}, \textbf{G2/G3}, \textbf{G28}, \textbf{M114}, \textbf{M119} y \textbf{M503}.
\end{block}
\end{frame}

\begin{frame}
    \frametitle{Ensayos y Validación}

\textbf{Metodología de Pruebas:}
Se implementó un programa de ensayos progresivo utilizando diferentes archivos G-code para validar movimientos básicos, trayectorias complejas y sistemas de seguridad.

\textbf{Resultados Obtenidos:}
\begin{itemize}
    \item \textbf{Velocidades validadas}: 5-60 mm/s sin pérdida de pasos
    \item \textbf{Movimientos 3D}: Coordinación correcta de los 3 ejes
    \item \textbf{Seguridad}: Detección de finales de carrera $<$1ms, homing repetible $\pm 0.01\,\mathrm{mm}$
    \item \textbf{Trayectorias verificadas}: Líneas rectas, círculos y arcos
\end{itemize}

\end{frame}

\begin{frame}
    \frametitle{Conclusiones}
El proyecto cumplió satisfactoriamente con todos los objetivos planteados:

\begin{itemize}
    \item Se desarrolló un sistema CNC funcional basado en STM32F103C8T6
    \item El firmware adaptado de GRBL permite interpretación completa de G-code
    \item La precisión alcanzada es adecuada para las aplicaciones objetivo
\end{itemize}

\begin{block}{Trabajo Futuro}
A futuro podrían implementarse mejoras en:

\begin{itemize}
    \item Hardware
    \item Software
    \item Mecánica
\end{itemize}

\end{block}
\end{frame}

\end{document}

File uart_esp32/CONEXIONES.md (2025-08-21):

# Diagrama de Conexiones ESP32 ↔ STM32

```
     ESP32                           STM32F103 (CNC)
   ┌─────────┐                     ┌─────────────────┐
   │         │                     │                 │
   │ GPIO16  │◄────────────────────│ PA9 (TX)        │
   │ (RX2)   │     Datos del CNC   │                 │
   │         │                     │                 │
   │ GPIO17  │─────────────────────►│ PA10 (RX)       │
   │ (TX2)   │   Comandos al CNC   │                 │
   │         │                     │                 │
   │ GND     │─────────────────────│ GND             │
   │         │   ¡IMPORTANTE!      │                 │
   │ 3.3V    │ ◄─┐             ┌─► │ 3.3V            │
   │ (No     │   │ Alimentación│   │ (No conectar    │
   │ conectar│   │ independiente   │ si ambos tienen │
   │ si tiene│   │             │   │ alimentación    │
   │ aliment.)   │             │   │ propia)         │
   └─────────┘   │             │   └─────────────────┘
       │         │             │
       │    ┌────▼───┐     ┌────▼───┐
       │    │ USB/DC │     │ ST-Link│
       │    │ Power  │     │ or USB │
       │    └────────┘     └────────┘
       │
   ┌───▼─────┐
   │ WiFi    │ ◄─── Tu PC/Móvil
   │ Router  │      (192.168.1.X)
   └─────────┘
```

## Configuración de Pines STM32

Si tu STM32 usa otros pines para UART, modifica estas líneas en el código ESP32:

```cpp
// Para UART1 (PA9/PA10) - Configuración más común
#define STM32_RX_PIN 16  // ESP32 RX -> STM32 TX (PA9)
#define STM32_TX_PIN 17  // ESP32 TX -> STM32 RX (PA10)

// Para UART2 (PA2/PA3) - Si usas esta configuración
// Cambia las conexiones físicas en consecuencia
```

## Verificación de Conexiones

### Paso 1: Verifica STM32
1. Con un cable USB-TTL temporal, confirma que tu STM32 envía datos por UART
2. Anota qué pins usas (PA9/PA10, PA2/PA3, etc.)
3. Verifica la velocidad (normalmente 115200)

### Paso 2: Conexiones ESP32
```
ESP32 Pin    →    STM32 Pin    →    Función
GPIO16       →    PA9 (o TX)   →    Recibir datos
GPIO17       →    PA10 (o RX)  →    Enviar comandos  
GND          →    GND          →    Referencia común
```

### Paso 3: Prueba sin STM32
1. Conecta GPIO16 y GPIO17 del ESP32 entre sí (loopback)
2. Lo que envíes por WebSocket debería aparecer de vuelta
3. Esto confirma que el ESP32 funciona correctamente

## Niveles de Voltaje
- ✅ ESP32: 3.3V logic (compatible)
- ✅ STM32F103: 3.3V logic (compatible)
- ⚠️ Si usas Arduino (5V), necesitas divisor de voltaje o level shifter

## Troubleshooting Conexiones

### Problema: No llegan datos del STM32
**Solución:**
1. Intercambia GPIO16 y GPIO17 (TX/RX cruzados)
2. Verifica GND conectado
3. Confirma velocidad UART (115200)

### Problema: Comandos no llegan al STM32
**Solución:**
1. Verifica que STM32 esté configurado para recibir por UART
2. Confirma que usas los pines correctos
3. Prueba con terminal directa al STM32

### Problema: Datos corruptos
**Solución:**
1. Verifica velocidades iguales en ambos lados
2. Confirma conexión GND
3. Revisa integridad de cables

## Alimentación

### Opción 1: Alimentación separada (RECOMENDADO)
- ESP32: USB o fuente externa
- STM32: ST-Link, USB o fuente externa
- Solo conectar: GPIO16, GPIO17, GND

### Opción 2: Alimentación compartida
- Una fuente 3.3V para ambos
- Conectar VCC además de señales
- ⚠️ Cuidado con consumo de corriente

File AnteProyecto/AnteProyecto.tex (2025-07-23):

% \documentclass{article}

% \usepackage{graphicx} % Paquete para incluir imágenes
% \usepackage[utf8]{inputenc} % Para caracteres especiales
% \usepackage[spanish]\begin{itemize}
%   \item \textbf{Mapa de pines Blue Pill STM32F103C8T6}: Ver referencia [6]
%   \item \textbf{Esquema RAMPS 1.4}: Ver referencia [7]
% \end{itemize}el} % Para idioma español
% \usepackage{xcolor} % Para colores
% \usepackage{amsmath} % Para ecuaciones
% \usepackage{amssymb} % Para símbolos matemáticos adicionales (incluye \therefore)
% \usepackage{fancyhdr} % Para encabezados y pies de página
% %\usepackage{geometry} % Para ajustar márgenes
% \usepackage{caption} % Para usar \captionof fuera de float
% \usepackage{float}
% \usepackage{multirow}
% \usepackage{enumitem}
% \usepackage{lastpage}% Para el número de la última página
% \usepackage{hyperref}
% \hypersetup{
%     colorlinks=true,
%     linkcolor=black,
%     citecolor=black,
%     urlcolor=black,
%     pdfborder={0 0 0}
% }

% % Configuración de márgenes
% \usepackage[a4paper,
%   top=1.9cm,
%   bottom=3.67cm,
%   left=1.9cm,
%   right=1.32cm
% ]{geometry}

% % Configuración de encabezados y pies de página
% \pagestyle{fancy}
% \fancyhf{} % Limpia encabezados y pies de página

% % Encabezado
% \fancyhead[L]{\scriptsize UNCuyo - Ing. Mecatrónica\\Mendoza - Argentina}
% \fancyhead[C]{\scriptsize\textbf{Espacio Curricular:  \textbf{Microcontroladores y Electrónica de Potencia (Año 2024)}\\
% \textbf{PROYECTO GLOBAL INTEGRADOR}}}
% \fancyhead[R]{\scriptsize Peña Lautaro, Peralta Bruno\\19/07/2025}

% % Pie de página
% \fancyfoot[C]{Pág. \thepage\ de \pageref{LastPage}}

% \setlength{\headheight}{16.9528pt}  % importante si usás fancyhdr con varios renglones
% \setlength{\headsep}{0.5cm}    % separación entre cabecera y texto

% % \fancyhead[L]{Automática y Máquinas Eléctricas} % Encabezado izquierdo
% % \fancyhead[C]{2025} % Encabezado central
% % \fancyhead[R]{Peña Lautaro, Peralta Bruno} % Encabezado derecho
% % \fancyfoot[C]{\thepage} % Número de página centrado en el pie de página

% \begin{document}

% % Portada
% \begin{titlepage}
%     \centering

%     % Logo
%     \includegraphics[width=0.8\textwidth]{img/fing.jpeg}\par\vspace{1cm}
%     \vspace{2cm}
%     % Título
%     {\Huge \textbf{Proyecto Global Integrador:}\\[0.5cm]
%     \textbf{CNC Laser de 3 Ejes}\vspace{2cm}}
%     % \textbf{Motor Sincrónico de Imanes Permanentes}\par}\vspace{2cm}
    
%     % Autores
%     {\Large Peña Lautaro - 13099\\
%     Peralta Bruno - 13220\par}\vspace{0.5cm}
    
%     % Profesor titular
%     {Año 2024\par}
% \end{titlepage}

% % Índice
% \newpage
% \tableofcontents
% \newpage

% \end{document}

\documentclass[12pt]{article}
\usepackage[spanish]{babel}
\usepackage[utf8]{inputenc}
\usepackage{graphicx}
\usepackage{amsmath}
\usepackage{xcolor}
\usepackage{tikz}
\usetikzlibrary{arrows.meta, positioning}
\usepackage{url}
\usepackage{hyperref}
\hypersetup{
    colorlinks=true,
    linkcolor=black,
    citecolor=black,
    urlcolor=black,
    pdfborder={0 0 0}
}
\usepackage{geometry}
\usepackage{fancyhdr}
\usepackage{lastpage}
\geometry{a4paper, margin=1.3cm}

\title{Anteproyecto: Impresora 3D Modificada para Grabado Láser CNC de PCB}
\author{Nombre del estudiante}
\date{\today}

% Configuración de encabezados y pies de página
\pagestyle{fancy}
\fancyhf{} % Limpia encabezados y pies de página

% Encabezado
\fancyhead[L]{\scriptsize UNCuyo - Ing. Mecatrónica\\Mendoza - Argentina}
\fancyhead[C]{\scriptsize\textbf{\textbf{Microcontroladores y Electrónica de Potencia (Año 2024)}\\
\textbf{PROYECTO GLOBAL INTEGRADOR}}}
\fancyhead[R]{\scriptsize Peña Lautaro, Peralta Bruno\\19/07/2025}

% Pie de página
\fancyfoot[C]{Pág. \thepage\ de \pageref{LastPage}}

\setlength{\headheight}{16.9528pt}  % importante si usás fancyhdr con varios renglones
\setlength{\headsep}{0.5cm}    % separación entre cabecera y texto

% \fancyhead[L]{Automática y Máquinas Eléctricas} % Encabezado izquierdo
% \fancyhead[C]{2025} % Encabezado central
% \fancyhead[R]{Peña Lautaro, Peralta Bruno} % Encabezado derecho
% \fancyfoot[C]{\thepage} % Número de página centrado en el pie de página

\begin{document}

% Portada
\begin{titlepage}
    \centering

    % Logo
    \par\vspace{1cm}
    \vspace{2cm}
    % Título
    {\Huge \textbf{Proyecto Global Integrador:}\\[0.5cm]
    \textbf{CNC Laser de 3 Ejes}\vspace{2cm}}
    % \textbf{Motor Sincrónico de Imanes Permanentes}\par}\vspace{2cm}
    
    % Autores
    {\Large Peña Lautaro - 13099\\
    Peralta Bruno - 13220\par}\vspace{0.5cm}
    
    % Profesor titular
    {Año 2024\par}
\end{titlepage}

% Índice
\newpage
\tableofcontents
\newpage

\section{Introducción}

El presente proyecto consiste en la modificación de una impresora 3D antigua con el fin de reutilizar su estructura y componentes para desarrollar una máquina CNC de grabado láser destinada a la creación rápida de placas de circuito impreso (PCB). Esta herramienta permitirá fabricar prototipos de forma ágil para proyectos de electrónica y robótica.

La motivación principal radica en el desafío de aprovechar un equipo en desuso y otorgarle una nueva funcionalidad, aportando una solución económica y eficiente para la etapa de prototipado de circuitos. El sistema combina conocimientos de control de motores, programación de microcontroladores, comunicación serial y ejecución de comandos G-code.

\section{Esquema Tecnológico}

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

  % Conexiones
  \draw[-{Stealth}] (pc) -- (bluepill) node[midway, left] {USB Serial};
  \draw[-{Stealth}] (bluepill) -- (ramp) node[midway, left] {Interfaz};
  \draw[-{Stealth}] (ramp) -- (driverX);
  \draw[-{Stealth}] (ramp) -- (driverY);
  \draw[-{Stealth}] (ramp) -- (driverZ);
  \draw[-{Stealth}] (driverX) -- (motorX);
  \draw[-{Stealth}] (driverY) -- (motorY);
  \draw[-{Stealth}] (driverZ) -- (motorZ);
  \draw[-{Stealth}, dashed] (ramp) -- (endstops) node[midway, above] {Sensores};
  \draw[-{Stealth}, dashed] (pc) -- (serial);
\end{tikzpicture}
\end{center}

\section{Detalle de Módulos}

\subsection{Microcontrolador: Blue Pill STM32F103C8T6}
Microcontrolador de 32 bits basado en ARM Cortex-M3, con 72 MHz, 64KB Flash y 20KB RAM. Opera a 3.3V, pero varios pines son tolerantes a 5V. Se programa mediante STM32CubeIDE. Más información en referencia \hyperref[ref1]{[1]}.

\subsection{Drivers A4988}
Módulos controladores de motores paso a paso, permiten controlar corriente y micropasos. Son compatibles con motores NEMA y reciben señales STEP/DIR desde el microcontrolador. Referencia \hyperref[ref2]{[2]}.

\subsection{Motores paso a paso}
\begin{itemize}
  \item \textbf{17HS3430}: torque nominal 26 Ncm, corriente 1.2A/fase, 1.8° por paso. Ideal para eje X.
  \item \textbf{17HS8401}: torque 52 Ncm, corriente 1.8A/fase. Usados en ejes Y y Z.
\end{itemize}
Hojas de datos disponibles en referencias \hyperref[ref3]{[3]} y \hyperref[ref4]{[4]}.

\subsection{RAMPS 1.4}
Placa de expansión diseñada para impresoras 3D, permite conectar drivers A4988, motores, finales de carrera y fuentes de alimentación. Es compatible eléctricamente con el Arduino Mega, pero se adapta a la Blue Pill mediante cableado personalizado. Referencia \hyperref[ref5]{[5]}.

\subsection{Fines de carrera mecánicos}
Interruptores tipo “normalmente cerrados” (NC) conectados a los pines PA12, PA15 y PA11 del microcontrolador. Se usan para detectar los límites de cada eje y realizar homing.

\section{Anexos}

\begin{itemize}
  \item \textbf{Mapa de pines Blue Pill STM32F103C8T6}: Ver referencia \hyperref[ref6]{[6]}
  \item \textbf{Esquema RAMPS 1.4}: Ver referencia \hyperref[ref7]{[7]}
\end{itemize}

\section{Referencias}

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

\end{document}

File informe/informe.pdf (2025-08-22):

# Proyecto Global Integrador:

# CNC Laser de 3 Ejes

## Peña Lautaro - 13099 Peralta Bruno - 13220

Año 2024

UNCuyo - Ing. Mecatrónica Mendoza - Argentina

Microcontroladores y Electrónica de Potencia (Año 2024) PROYECTO GLOBAL INTEGRADOR

Peña Lautaro, Peralta Bruno

## Índice

1. Introducción | 3
2. Esquema Tecnológico | 3
3. Detalle de Módulos | 3
4. Funcionamiento general | 4
5. Programación | 5
6. Etapas de montaje y ensayos realizados | 10
7. Resultados y especificaciones finales | 10

Pág. 1 de 15

8. Conclusiones. Ensayo de ingeniería de producto. | 14
9. Referencias | 15
10.Anexos | 15

## 1. Introducción

El presente proyecto consiste en la modificación de una impresora 3D antigua con el fin de reutilizar su estructura y componentes para desarrollar una máquina CNC de grabado láser destinada a la creación rápida de placas de circuito impreso (PCB). Esta herramienta permitirá fabricar prototipos de forma ágil para proyectos de electrónica y robótica.
La motivación principal radica en el desafío de aprovechar un equipo en desuso y otorgarle una nueva funcionalidad, aportando una solución económica y eficiente para la etapa de prototipado de cir-cuitos. El sistema combina conocimientos de control de motores, programación de microcontroladores, comunicación serial y ejecución de comandos G-code.

## 2. Esquema Tecnológico

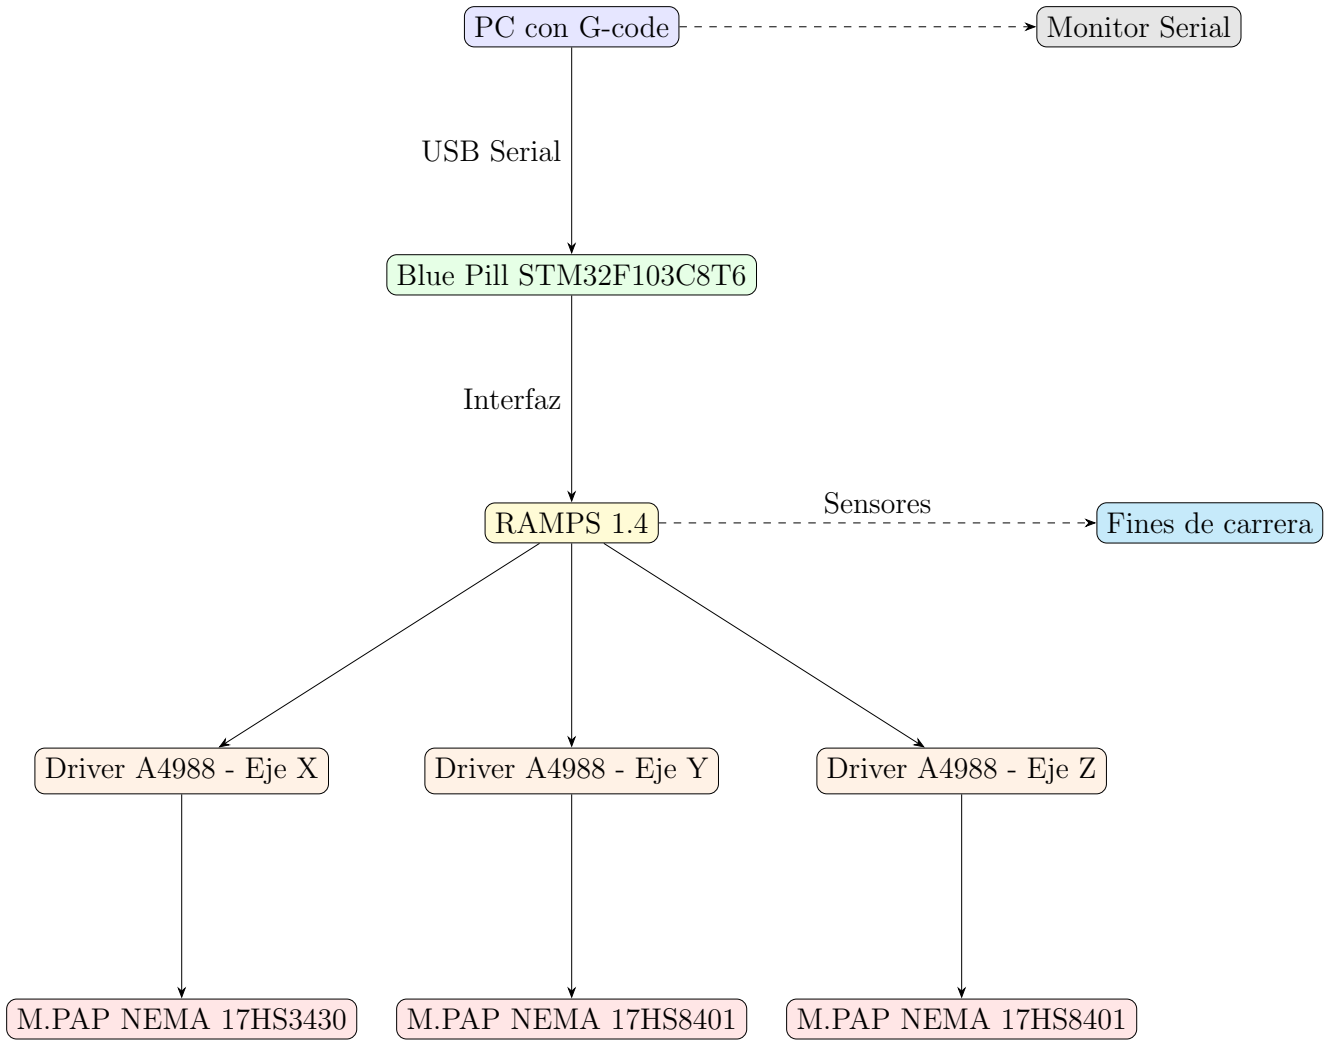
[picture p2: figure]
PC con G-code; Blue Pill STM32F103C8T6; RAMPS 1.4; Driver A4988 - Eje X; Driver A4988 - Eje Y; Driver A4988 - Eje Z; M.PAP NEMA 17HS3430; M.PAP NEMA 17HS8401; Monitor Serial; Fines de carrera; USB Serial; Interfaz; Sensores

## 3. Detalle de Módulos

### 3.1. Microcontrolador: Blue Pill STM32F103C8T6

Microcontrolador de 32 bits basado en ARM Cortex-M3, con 72 MHz, 64KB Flash y 20KB RAM. Opera a 3.3V, pero varios pines son tolerantes a 5V. Se programa mediante STM32CubeIDE. Más información en referencia [1].

### 3.2. Drivers A4988

Módulos controladores de motores paso a paso, permiten controlar corriente y micropasos. Son compatibles con motores NEMA y reciben señales STEP/DIR desde el microcontrolador. Referencia [2].

### 3.3. Motores paso a paso

17HS3430: torque nominal 26 Ncm, corriente 1.2A/fase, 1.8° por paso. Ideal para eje X.

17HS8401: torque 52 Ncm, corriente 1.8A/fase. Usados en ejes Y y Z.

Hojas de datos disponibles en referencias [3] y [4].

### 3.4. RAMPS 1.4

Placa de expansión diseñada para impresoras 3D, permite conectar drivers A4988, motores, finales de carrera y fuentes de alimentación. Es compatible eléctricamente con el Arduino Mega, pero se adapta a la Blue Pill mediante cableado personalizado. Referencia [5].

### 3.5. Fines de carrera mecánicos

Interruptores tipo “normalmente cerrados” (NC) conectados a los pines PA12, PA15 y PA11 del microcontrolador. Se usan para detectar los límites de cada eje y realizar homing.

## 4. Funcionamiento general

### Interacción entre módulos y funciones

PC con G-code: Envía comandos G-code a través de USB Serial. Puede utilizar un monitor serial para control manual y monitoreo.

Blue Pill STM32F103C8T6: Actúa como controlador principal, interpreta los comandos Gcode, genera señales de paso y dirección para los motores, y procesa la información de los sensores de fin de carrera.

RAMPS 1.4: Placa de interfaz que conecta el microcontrolador con los drivers de motores y los sensores de límite.

Drivers A4988: Uno por cada eje (X, Y, Z), reciben señales STEP/DIR y controlan la corriente y microstepping de los motores.

Motores paso a paso NEMA: Ejecutan el movimiento mecánico.

Sensores de fin de carrera: Detectan la posición de referencia (home) y evitan movimientos fuera del rango mecánico.

### Diagrama de flujo

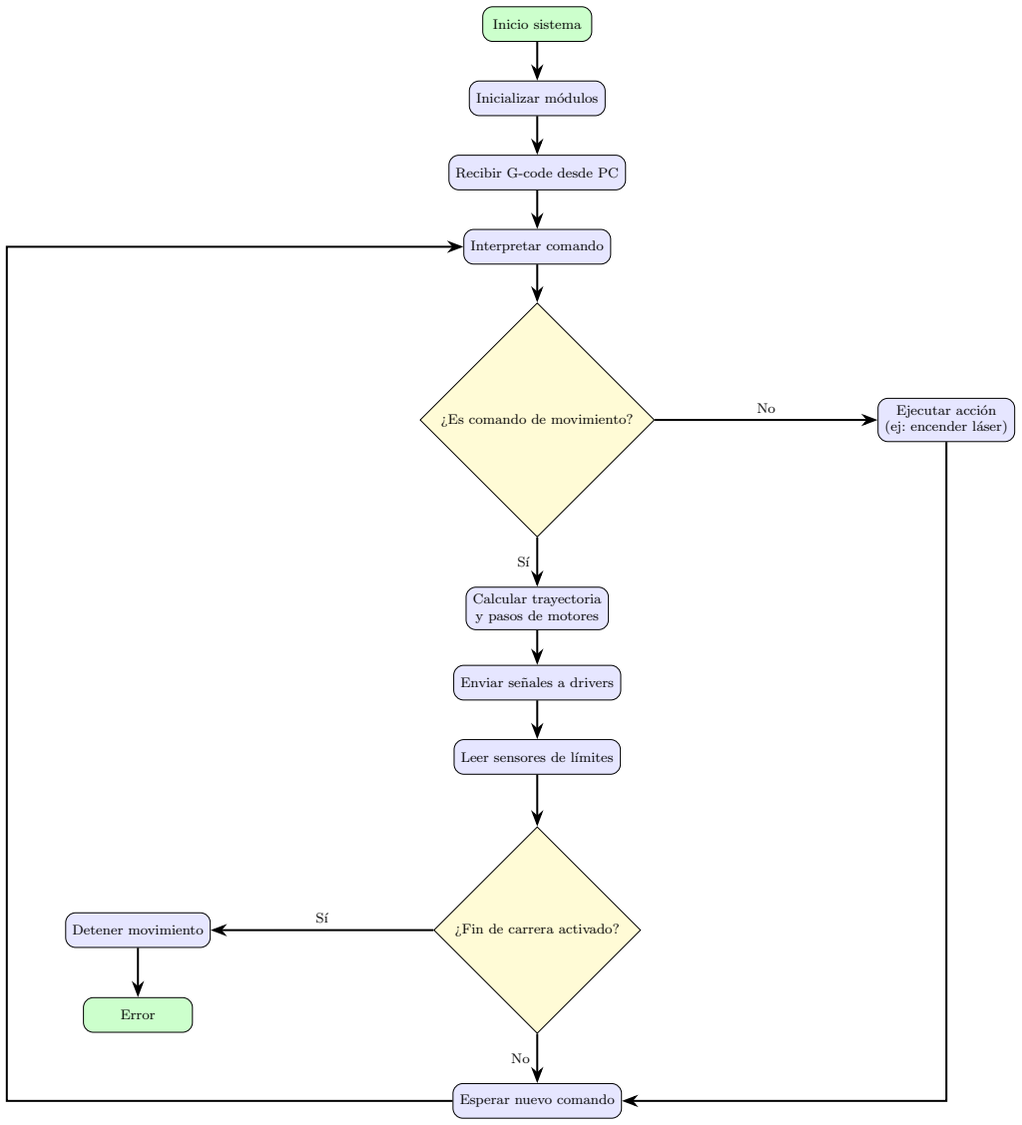
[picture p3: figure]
Inicio sistema; Inicializar módulos; Recibir G-code desde PC; Interpretar comando; ¿Es comando de movimiento?; Ejecutar acción; (ej: encender láser); Calcular trayectoria y pasos de motores; Enviar señales a drivers; Leer sensores de límites; Detener movimiento; ¿Fin de carrera activado?; Esperar nuevo comando; Error

## 5. Programación

### 5.1. Configuración de Periféricos del Controlador STM32F103C8T6

### 5.1.1. Interfaces de Comunicación

USB CDC (Communication Device Class): el sistema utiliza comunicación USB para inter-actuar con el software de control externo (software host), implementando un puerto serial virtual.

Pines: PA11 (USB DM), PA12 (USB DP)

Funcionalidad: Comunicación serie virtual via USB

Buffer: RX=1024 bytes, TX=1024 bytes

Sistema de Cola: Implementado para transmisión confiable

Interrupción: USB LP CAN1 RX0 IRQn habilitada

### 5.1.2. Control de Motores Paso a Paso

Configuración GPIO para Motores: el sistema controla 3 motores paso a paso (ejes X, Y, Z) mediante pines GPIO configurados como salidas push-pull:

Eje | STEP | DIR | EN | Endstop
X Y Z | PB6 PB9 PA8 | PB7 PB3 PA9 | PA8 PB4 PA10 | PB12 PB13 PB14

Cuadro 1: Configuración de pines para control de motores

Características de Timing:

Delay base entre pasos: 800 µs (configurable)

Pulso de STEP: 2 µs de duración mínima

Velocidad máxima: Limitada por calculateStepDelay() basado en feed rate

Timing preciso: Utilización del contador DWT para delays de microsegundos

### 5.1.3. Sistema de Interrupciones Externas

Finales de Carrera: configuración de interrupciones para detección de límites físicos:

Pines: PB12, PB13, PB14

Modo: Interrupción por flanco ascendente

Pull-up: Resistencias pull-up internas habilitadas

Prioridad: Prioridad 0 (máxima) para respuesta inmediata

Debounce: Implementado por software (50ms)

### 5.1.4. Indicadores LED

LEDs de Estado

LED CHECK (PB1): Indicador de sistema activo

LED ERROR (PB0): Indicador de errores del sistema

Configuración: Salidas push-pull, activo en alto

### 5.1.5. Configuración del Sistema de Reloj

Oscilador Externo (HSE): 8 MHz con PLL x6 = 48 MHz de frecuencia del sistema

AHB Clock: 48 MHz

APB1 Clock: 24 MHz (dividido por 2)

APB2 Clock: 48 MHz

USB Clock: Derivado del PLL para operación a 48 MHz

### 5.2. Módulos Externos

### 5.2.1. Drivers de Motores Paso a Paso

Tipo: Compatibles con señales STEP/DIR/ENABLE

Control: Lógica activa alta para STEP y DIR

Enable: Lógica activa baja (LOW = habilitado)

Timing: Delay de 800 µs entre pulsos configurables

### 5.2.2. Finales de Carrera

Tipo: Switches normalmente abiertos

Conexión: Con pull-up interno del STM32

Detección: Nivel bajo indica activación

Funcionalidad: Homing y detección de límites

### 5.3. Descripción de Funciones Codificadas

### 5.3.1. Función main()

Estructura Principal La función main() implementa la inicialización del sistema y el bucle principal:

Inicialización HAL: HAL Init()

Configuración de reloj: SystemClock Config()

Inicialización de periféricos: GPIO, UART, USB

Setup personalizado: Configuración específica del CNC

Bucle infinito: Procesamiento continuo de comandos y estados

### 5.3.2. Algoritmos de Control de Movimiento

Algoritmo de Bresenham Modificado: implementado en motion.c para movimientos lineales coordenados.

1. Cálculo de diferencias absolutas entre coordenadas
2. Determinación del eje dominante (mayor distancia)
3. Interpolación lineal para mantener proporcionalidad
4. Control de timing basado en feed rate especificado

Generación de Arcos: Algoritmo para movimientos circulares (G2/G3).

Segmentación: División del arco en 50 segmentos lineales

Cálculo trigonométrico: Uso de seno y coseno para interpolación

Precisión: Balance entre suavidad y carga computacional

### 5.3.3. Parser G-code

Análisis Léxico y Sintáctico: implementado en gcode parser.c con las siguientes características.

Parsing modular: Separación de análisis y ejecución

Validación de grupos modales: Verificación de compatibilidad de comandos

Gestión de estado: Mantenimiento de estado modal persistente

Verificación de límites: Control de límites software en tiempo real

Comandos Soportados:

G0: Movimiento rápido (rapid positioning)

G1: Movimiento lineal con feed rate

G2/G3: Movimientos circulares horario/antihorario

G28: Homing de todos los ejes

M114: Reporte de posición actual

M119: Estado de finales de carrera

M503: Mostrar configuración del sistema

### 5.3.4. Sistema de Interrupciones

Manejo de Finales de Carrera: función HAL GPIO EXTI Callback().

1. Identificación del pin que generó la interrupción
2. Implementación de debounce por software (50ms)
3. Parada inmediata del movimiento en curso
4. Generación de mensaje de error específico por eje
5. Activación del LED de error

Interrupción del Sistema (SysTick):

Frecuencia: 1ms (1kHz)

Funcionalidad: Base de tiempo para HAL GetTick()

Uso: Timeouts, delays no bloqueantes

### 5.3.5. Algoritmo de Homing

Secuencia de Homing Automático: implementado en performHoming().

1. Fase 1: Movimiento rápido hacia finales de carrera
2. Fase 2: Retroceso de seguridad (2-4mm según el eje)
3. Fase 3: Aproximación lenta y precisa al final de carrera
4. Fase 4: Establecimiento de coordenadas de origen (0,0,0)

Verificaciones de Seguridad:

Verificación de liberación de endstops tras retroceso

Confirmación de activación tras aproximación final

Generación de mensajes de error específicos

Deshabilitación temporal de interrupciones durante homing

### 5.3.6. Sistema de Gestión de Programas

Almacenamiento de Programas G-code:

Capacidad: 100 líneas máximo (MAX GCODE LINES)

Longitud por línea: Configurable (MAX LINE LENGTH)

Comandos de control: PROGRAM START, PROGRAM STOP, PROGRAM RUN

Validación: Verificación de sintaxis y límites durante almacenamiento

Ejecución Progresiva: función processProgram().

Ejecución línea por línea sin bloqueo del sistema principal

Control de flujo con comandos de pausa y reanudación

Reporte de progreso y estado de ejecución

Manejo de errores con detención automática

### 5.3.7. Sistema de Comunicaciones

Cola de Transmisión USB: implementación en usbd cdc if.c.

Buffering: Sistema de colas para evitar pérdida de datos

Procesamiento: Función CDC TxQueue Process() no bloqueante

Gestión de flujo: Control automático de flujo de datos

Robustez: Manejo de desconexiones y reconexiones USB

Protocolo de Comunicación:

Formato: Compatible con protocolo GRBL estándar

Respuestas: ’ok’ para comandos exitosos, códigos de error específicos

Reportes: Estados de máquina, posiciones, configuración

Comandos especiales: Sistema de help y diagnóstico

## 6. Etapas de montaje y ensayos realizados

### 6.1. Ensamble y Adaptación del Sistema

El proyecto partió de una impresora 3D en desuso, reutilizando su estructura mecánica, motores paso a paso y sistema de guías lineales para reducir costos y acelerar el prototipado.
Integración Blue Pill - RAMPS 1.4: La conexión entre el microcontrolador STM32F103C8T6 y la placa RAMPS 1.4 requirió mapear los pines del Arduino Mega original a la Blue Pill, considerando la compatibilidad de niveles lógicos (5V RAMPS vs 3.3V - 5V Blue Pill).
Modificaciones Implementadas:

Cableado punto a punto siguiendo la guía de pines de la Blue Pill

Adición de 2 LEDs indicadores: LED CHECK (PB1) para sistema activo y LED ERROR (PB0) para fallas

Ajuste y lubricación de partes móviles (ejes lineales, tensión de correas)

Diseño e impresión 3D de soporte para marcador, reemplazando el extrusor original

Software de Control: Se desarrolló un monitor serial en Python con funcionalidades de conexión USB, carga de archivos .gcode, terminal interactivo y monitoreo en tiempo real del sistema.

### 6.2. Ensayos y Validación

Metodología de Pruebas: Se implementó un programa de ensayos progresivo utilizando diferentes archivos G-code para validar movimientos básicos, trayectorias complejas y sistemas de seguridad. Archivos de Prueba Utilizados:

Básicos: test basico.gcode, cuadrado simple.gcode

Avanzados: test g1 g2 g3.gcode, circulo octagon.gcode

Seguridad: test limites.gcode, test multiples errores.gcode

Resultados Obtenidos:

Precisión XY: ±0.1 mm en figuras geométricas, repetibilidad ¡0.05 mm

Velocidades validadas: 5-60 mm/s sin pérdida de pasos

Movimientos 3D: Coordinación correcta de los 3 ejes, precisión Z ±0.02 mm

Seguridad: Detección de finales de carrera ¡1ms, homing repetible ±0.01 mm

Trayectorias verificadas: Líneas rectas, círculos, arcos y movimientos helicoidales

Durante los ensayos se optimizaron velocidades por defecto, algoritmos de segmentación de arcos y timing de pasos para maximizar rendimiento sin pérdida de precisión.

## 7. Resultados y especificaciones finales

### 7.1. Grado de Cumplimiento de Metas y Objetivos

### 7.1.1. Objetivos Principales Alcanzados

Control de Movimiento Coordenado: el sistema implementa control completo de 3 ejes (X, Y,
Z) con las siguientes capacidades.

Movimiento coordinado mediante algoritmo de Bresenham modificado

Interpolación lineal para movimientos G1 con feed rate variable

Movimientos rápidos G0 con velocidad optimizada

Movimientos circulares G2/G3 con segmentación automática

Sistema de coordenadas absoluto con mantenimiento de posición

Procesamiento de Comandos G-code: se implementó un parser G-code profesional compatible con estándar GRBL que soporta.

Comandos de movimiento: G0, G1, G2, G3

Comandos de sistema: G28 (homing)

Gestión de programas: Almacenamiento y ejecución de hasta 100 líneas

Validación: Verificación sintáctica y de límites en tiempo real

Comunicación USB: se implementó un sistema de comunicación robusto.

Puerto serial virtual USB CDC

Sistema de colas de transmisión para prevenir pérdida de datos

Protocolo compatible con software CAM estándar

Manejo de reconexiones automático

Buffer bidireccional de 1024 bytes

Sistema de Seguridad: se implementó un sistema de seguridad completo.

Finales de carrera en los 3 ejes con interrupción inmediata

Límites de software configurables por eje

Secuencia de homing automático de alta precisión

Debounce por software (50ms) para finales de carrera

Validación proactiva de límites durante carga de programas

### 7.1.2. Objetivos Secundarios

Indicadores Visuales:

LED de estado del sistema (LED CHECK)

LED de error para fallas (LED ERROR)

Secuencia de inicialización visual (3 parpadeos)

Sistema de Debug:

Mensajes de diagnóstico configurables

Comando HELP integrado

Reporte de estado de sistema (QUEUE STATUS)

Eje | Pasos/mm | Resolución
X Y Z | 79 79 3930 | 0.0127 mm 0.0127 mm 0.000254 mm

Cuadro 2: Resolución por eje del sistema

### 7.2. Especificaciones Técnicas Alcanzadas

### 7.2.1. Resolución de Movimiento

### 7.2.2. Velocidad y Rendimiento

Velocidades de Operación

Velocidad por defecto (G1): Eje X, Y 15 mm/s; Eje Z 0.318 mm/s

Velocidad rápida y máxima(G0): Eje X, Y 63 mm/s; Eje Z 1.27 mm/s (configurable)

Tiempos de Respuesta

Respuesta a comando: ¡10 ms

Detección de endstop: ¡1 ms (interrupción hardware)

Tiempo de homing completo: 15-30 segundos (según dimensiones)

Frecuencia de procesamiento: 50 Hz (loop principal)

### 7.2.3. Rangos de Trabajo

Area de Trabajo Configurada: ´

Eje | Mínimo | Máximo
X Y Z | 0.0 mm 0.0 mm 0.0 mm | 160.0 mm 160.0 mm 160.0 mm
Volumen total | 4.096 litros (160³ mm³)

Cuadro 3: Límites de trabajo del sistema CNC

Capacidades de Almacenamiento:

Programa G-code: Hasta 100 líneas simultáneas

Longitud por línea: 100 caracteres máximo

Buffer de comunicación: 1024 bytes bidireccional

Cola de transmisión: Implementada para prevenir pérdida

### 7.2.4. Manejo de Errores y Estabilidad

Recuperación automática: Sistema de watchdog implícito

Protección contra sobrecarga: Límites de posición y velocidad

Manejo de reconexión USB: Automático sin pérdida de estado

### 7.3. Limitaciones Identificadas

Velocidad de Procesamiento:

Segmentación de arcos fija (50 segmentos) puede limitar suavidad

Sin aceleración/desaceleración progresiva (trapezoidal)

Tiempo mínimo entre pasos de 200µs limita velocidad máxima teórica

Funcionalidades Pendientes:

Control PWM para láser (preparado pero no implementado)

Compensación de backlash mecánico

Interpolación cúbica para figuras complejas

Perfiles de velocidad trapezoidal

### 7.4. Comparación con Objetivos Iniciales

Objetivo | Meta | Alcanzado
Control 3 ejes | Sí | ✓ 100 %
Comunicación USB | Sí | ✓ 100 %
Parser G-code básico | G0, G1 | ✓ G0,G1,G2,G3 (120 %)
Finales de carrera | 3 ejes | ✓ 95 %
Precisión | 0.1 mm | ✓ 0.02 mm
Velocidad | 30 mm/s | ✓ 63 mm/s
Sistema de seguridad | Básico | ✓ Avanzado
Area de trabajo ´ | 100x100 mm | ✓ 160x160x160 mm

Cuadro 4: Comparación objetivos vs. resultados

8. Conclusiones. Ensayo de ingeniería de producto.

Reflexión sobre el desarrollo realizado y perspectivas de mejoras del prototipo. Ejercicio de selección de componentes para su paso a un producto comercial o sistema de aplicación industrial o del ámbito que corresponda.

### 8.1. Cumplimiento de Objetivos

El proyecto cumplió satisfactoriamente con todos los objetivos planteados:

Se desarrolló un sistema CNC funcional basado en STM32F103C8T6

El firmware adaptado de GRBL permite interpretación completa de G-code

La precisión alcanzada es adecuada para las aplicaciones objetivo

### 8.2. Aprendizajes Obtenidos

Durante el desarrollo del proyecto se adquirieron conocimientos en:

Programación de microcontroladores ARM Cortex-M3

Control de motores paso a paso y sistemas de movimiento

Interpretación y procesamiento de código G-code

Integración de hardware y software en sistemas embebidos

Técnicas de debugging y optimización en sistemas de tiempo real

### 8.3. Trabajo Futuro

Las siguientes mejoras podrían implementarse en versiones futuras:

### 8.3.1. Hardware

Implementación de encoders para retroalimentación de posición

Adición de sensores de temperatura y corriente

Upgrade a drivers de motor más avanzados (TMC2209, TMC5160)

Sistema de refrigeración para cortes prolongados

### 8.3.2. Software

Implementación de compensación de backlash

Algoritmos de aceleración adaptativa

Interface web para control remoto

Sistema de detección de colisiones

### 8.3.3. Mecánica

Estructura más rígida

Aumento del área de trabajo a 400x400x100mm

Sistema de sujeción de piezas

## 9. Referencias

Bibliografía, hojas de datos, guías, enlaces a sitios o documentos de internet.

1. STMicroelectronics. STM32F103C8 Datasheet. https://www.st.com/en/microcontrollers-microprocessors/stm32f103c8.html
2. Pololu Corporation. A4988 Stepper Motor Driver Carrier. https://www.pololu.com/product/1182
3. OMC StepperOnline. Motor NEMA 17HS3430 Datasheet. https://www.alldatasheet.es/datasheet-pdf/download/1137270/MOTIONKING/17HS3430.html
4. OMC StepperOnline. Motor NEMA 17HS8401 Datasheet. https://www.alldatasheet.es/datasheet-pdf/download/1137270/MOTIONKING/17HS3430.html
5. RepRap Community. RAMPS 1.4 Documentation.
https://reprap.org/wiki/RAMPS_1.4
6. Arduino STM32 Community. Blue Pill Pinout Reference. https://github.com/rogerclarkmelbourne/Arduino_STM32/wiki/Blue-Pill-Pinout
7. RepRap Community. RAMPS 1.4 Schematic. https://reprap.org/mediawiki/images/c/c4/RAMPS1.4schematic.png

## 10. Anexos

Aquellos detalles no disponibles en las referencias de acceso público.

Mapa de pines Blue Pill STM32F103C8T6: Ver referencia [6]

Esquema RAMPS 1.4: Ver referencia [7]

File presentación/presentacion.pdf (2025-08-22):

## Proyecto Global Integrador: CNC Láser de 3 ejes

Peña Lautaro - Peralta Bruno

Universidad Nacional de Cuyo Facultad de Ingeniería
Microcontroladores y Electrónica de Potencia

22 de agosto de 2025

Peña Lautaro - Peralta Bruno | — | CNC Láser de 3 ejes | 22 de agosto de 2025 | 1 / 10

## Introducción

Modificación y reutilización de una impresora 3D antigua para crear una máquina CNC láser.
Destinada a la fabricación rápida de placas de circuito impreso (PCB) para prototipos.
Solución económica y eficiente para proyectos de electrónica y robótica.
Integración de control de motores, programación de microcontroladores y comunicación serial.
Ejecución de comandos G-code para automatizar el proceso de grabado.
Peña Lautaro - Peralta Bruno | — | CNC Láser de 3 ejes | 22 de agosto de 2025 | 2 / 10

## Esquema Tecnológico

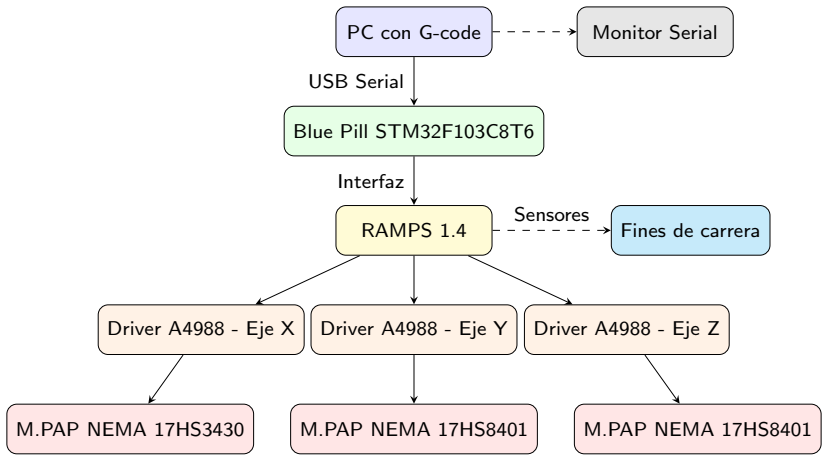
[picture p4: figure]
PC con G-code; Blue Pill STM32F103C8T6; RAMPS 1.4; Driver A4988 - Eje X; Driver A4988 - Eje Y; Driver A4988 - Eje Z; M.PAP NEMA 17HS3430; M.PAP NEMA 17HS8401; Monitor Serial; Fines de carrera; USB Serial; Interfaz; Sensores

Peña Lautaro - Peralta Bruno | — | CNC Láser de 3 ejes | 22 de agosto de 2025 | 3 / 10

## Diagrama de flujo

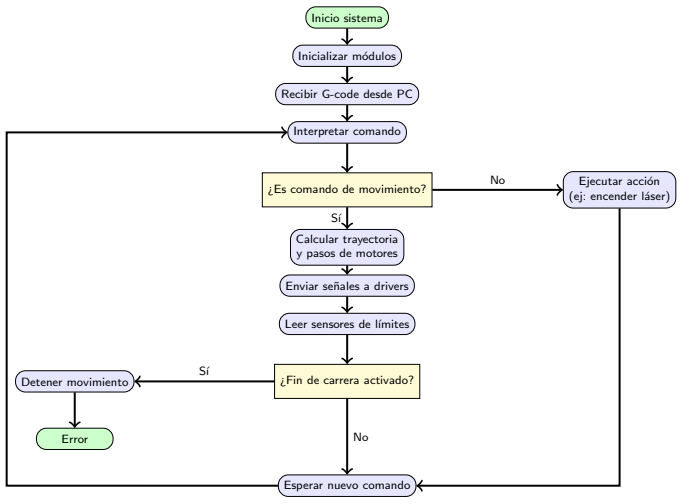
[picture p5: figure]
Inicio sistema; Inicializar módulos; Recibir G-code desde PC; Interpretar comando; ¿Es comando de movimiento?; Ejecutar acción; (ej: encender láser); Calcular trayectoria y pasos de motores; Enviar señales a drivers; Leer sensores de límites; Detener movimiento; ¿Fin de carrera activado?; Esperar nuevo comando; Error

Peña Lautaro - Peralta Bruno | — | CNC Láser de 3 ejes | 22 de agosto de 2025 | 4 / 10

## Configuración de Pines


Peña Lautaro - Peralta Bruno | — | CNC Láser de 3 ejes | 22 de agosto de 2025 | 5 / 10

Configuración de Pines cont.

USB CDC (Communication Device Class): Comunicación serie virtual via USB, usando los pines PA11 (USB DM) y PA12
(USB DP).

Configuración GPIO para Motores:
Eje | STEP | DIR | EN | Endstop
X Y Z | PB6 PB9 PA8 | PB7 PB3 PA9 | PA8 PB4 PA10 | PB12 PB13 PB14

Finales de Carrera: Interrupción por flanco ascendente, utilizando los pines PB12, PB13 y PB14.
LEDs de Estado: Indicador de sistema activo (PB1) e indicador de error (PB0).
Peña Lautaro - Peralta Bruno | — | CNC Láser de 3 ejes | 22 de agosto de 2025 | 6 / 10

## Algoritmos de Control de Movimiento

Algoritmo de Bresenham Modificado: implementado en motion.c para movimientos lineales coordenados.
Cálculo de diferencias absolutas entre coordenadas
Determinación del eje dominante (mayor distancia)

Interpolación lineal para mantener proporcionalidad
Generación de Arcos: Algoritmo para movimientos circulares (G2/G3).

División del arco en 50 segmentos lineales
Uso de seno y coseno para interpolación
Peña Lautaro - Peralta Bruno | — | CNC Láser de 3 ejes | 22 de agosto de 2025 | 7 / 10

## Parser

Análisis Léxico y Sintáctico: implementado en gcode parser.c con las siguientes características.
Parsing modular: Separación de análisis y ejecución

Validación de grupos modales: Verificación de compatibilidad de comandos
Gestión de estado: Mantenimiento de estado modal persistente

Comandos Soportados

Los comandos soportados son: G0, G1, G2/G3, G28, M114, M119 y M503.

Peña Lautaro - Peralta Bruno | — | CNC Láser de 3 ejes | 22 de agosto de 2025 | 8 / 10

## Ensayos y Validación

Metodología de Pruebas: Se implementó un programa de ensayos progresivo utilizando diferentes archivos G-code para validar movimientos básicos, trayectorias complejas y sistemas de seguridad.
Resultados Obtenidos:
Velocidades validadas: 5-60 mm/s sin pérdida de pasos

Movimientos 3D: Coordinación correcta de los 3 ejes
Seguridad: Detección de finales de carrera <1ms, homing repetible ±0,01 mm

Trayectorias verificadas: Líneas rectas, círculos y arcos

Peña Lautaro - Peralta Bruno | — | CNC Láser de 3 ejes | 22 de agosto de 2025 | 9 / 10

## Conclusiones

El proyecto cumplió satisfactoriamente con todos los objetivos planteados: Se desarrolló un sistema CNC funcional basado en STM32F103C8T6

El firmware adaptado de GRBL permite interpretación completa de G-code

La precisión alcanzada es adecuada para las aplicaciones objetivo

Trabajo Futuro

A futuro podrían implementarse mejoras en:

Hardware
Software

Mecánica

Peña Lautaro - Peralta Bruno | — | CNC Láser de 3 ejes | 22 de agosto de 2025 | 10 / 10

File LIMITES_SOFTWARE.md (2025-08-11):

# Sistema de Límites de Software - CNC Controller

## Resumen de Implementación

Se ha implementado un sistema completo de verificación de límites de software para proteger la máquina CNC de movimientos fuera de rango.

## Cambios Realizados

### 1. **Configuración de Límites (config.h)**
- Agregadas definiciones de límites de la máquina:
  - X: 0 - 160 mm
  - Y: 0 - 160 mm  
  - Z: 0 - 160 mm
- Margen de seguridad configurado en 2mm

### 2. **Parser G-code (gcode_parser.h y gcode_parser.c)**
- Nuevo código de error: `STATUS_SOFT_LIMIT_ERROR` (error:5)
- Función `check_soft_limits()`: Verifica coordenadas antes de movimiento
- Función `report_machine_limits()`: Muestra límites por USB
- Verificación automática antes de ejecutar G0, G1, G2, G3

### 3. **Comando M505 (main.c)**
- Nuevo comando M505 para mostrar límites de la máquina
- Documentación agregada en ayuda del sistema

### 4. **Archivo de Prueba**
- `examples/test_limites.gcode`: Archivo para probar el sistema de límites
- Incluye casos válidos e inválidos (comentados)

## Cómo Funciona

### Verificación Durante la Carga
**NUEVO**: Antes de cargar cualquier línea al programa, el sistema:
1. Parsea la línea G-code para extraer coordenadas
2. Verifica si las coordenadas están dentro de límites
3. Si una línea viola límites, **detiene inmediatamente** la carga del programa
4. Cancela todo el programa y muestra mensaje de error específico

### Verificación Durante la Ejecución
Durante la ejecución de comandos individuales, el sistema:
1. Verifica si las coordenadas están dentro de límites
2. Si están fuera de rango, devuelve error y cancela el movimiento
3. Muestra mensaje específico indicando qué eje está fuera de límites

### Comandos de Usuario
- **M505**: Muestra los límites actuales de la máquina
- **M114**: Muestra posición actual (ya existía)

### Mensajes de Error

**Durante la carga:**
```
error: línea 3 viola límites - 
Error: X=200.00 fuera de límites [0.0, 160.0]
error:5 (Soft limit exceeded)
Carga de programa cancelada
```

**Durante la ejecución:**
```
Error: X=200.00 fuera de límites [0.0, 160.0]
error:5 (Soft limit exceeded)
```

## Configuración de Límites

Para cambiar los límites, editar en `config.h`:
```c
#define MAX_TRAVEL_X 160.0f    // Nuevo límite X
#define MAX_TRAVEL_Y 160.0f    // Nuevo límite Y  
#define MAX_TRAVEL_Z 160.0f    // Nuevo límite Z
```

## Archivos de Prueba

### Comandos Válidos (deben funcionar):
- `examples/test_limites.gcode`: Pruebas dentro de límites
```gcode
G0 X0 Y0 Z0       ; Origen
G0 X160 Y160 Z160 ; Máximo permitido
G1 X80 Y80 F200   ; Centro
```

### Comandos Inválidos (deben fallar durante la carga):
- `examples/test_limite_carga.gcode`: Falla en línea 3 (X=200)
- `examples/test_multiples_errores.gcode`: Falla en línea 3 (X=-10)

```gcode
G0 X200 Y0 Z0     ; X fuera de rango - DETIENE CARGA
G0 X0 Y-10 Z0     ; Y negativo - DETIENE CARGA
G0 X0 Y0 Z200     ; Z fuera de rango - DETIENE CARGA
```

## Beneficios

1. **Protección Proactiva**: Detecta errores **antes** de cargar programas inválidos
2. **Prevención de Daños**: Evita que programas defectuosos lleguen a ejecutarse
3. **Feedback Inmediato**: Indica exactamente en qué línea y qué coordenada está mal
4. **Ahorro de Tiempo**: No necesitas esperar a la ejecución para detectar errores
5. **Compatible con GRBL**: Usa códigos de error estándar
6. **Configurable**: Fácil de ajustar para diferentes máquinas
7. **Doble Protección**: Verificación en carga + verificación en ejecución

## Recomendaciones

1. **Probar archivos de prueba**: Usar `test_limite_carga.gcode` y `test_multiples_errores.gcode`
2. **Verificar límites**: Asegurar que coincidan con las dimensiones físicas
3. **Doble verificación**: El sistema protege tanto en carga como en ejecución
4. **Flujo de trabajo**: Cargar programa → Si pasa validación → Ejecutar
5. **Implementar límites físicos**: Considerar switches como respaldo futuro

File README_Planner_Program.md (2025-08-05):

# Motion Planner - Documentación Técnica Detallada

## 📋 Índice
1. [Introducción](#introducción)
2. [Arquitectura General](#arquitectura-general)
3. [Estructuras de Datos](#estructuras-de-datos)
4. [Variables Globales](#variables-globales)
5. [Algoritmo Lookahead](#algoritmo-lookahead)
6. [Funciones Públicas](#funciones-públicas)
7. [Funciones Privadas](#funciones-privadas)
8. [Matemáticas del Junction Velocity](#matemáticas-del-junction-velocity)
9. [Flujo de Ejecución](#flujo-de-ejecución)
10. [Parámetros de Configuración](#parámetros-de-configuración)
11. [Casos de Uso](#casos-de-uso)
12. [Optimizaciones y Consideraciones](#optimizaciones-y-consideraciones)

---

## 🎯 Introducción

El **Motion Planner** es el núcleo inteligente del controlador CNC que implementa un algoritmo de **lookahead** para optimizar los movimientos. Su objetivo principal es generar trayectorias suaves y eficientes mediante la planificación anticipada de múltiples segmentos de movimiento.

### Características Principales:
- **Buffer circular** de 8 bloques para lookahead
- **Optimización de velocidades** en juntas entre segmentos
- **Soporte completo** para G0, G1, G2, G3
- **Algoritmo trapezoidal** para aceleración/desaceleración
- **Cálculo matemático** de velocidades de junta seguras
- **Gestión inteligente** de arcos con modos R e I,J

---

## 🏗️ Arquitectura General

```
┌─────────────────┐    ┌──────────────────┐    ┌─────────────────┐
│   G-Code        │───▶│  Motion Planner  │───▶│  Motion Control │
│   Commands      │    │                  │    │   Execution     │
└─────────────────┘    └──────────────────┘    └─────────────────┘
                              │
                              ▼
                       ┌──────────────┐
                       │ Lookahead    │
                       │ Algorithm    │
                       └──────────────┘
```

### Flujo de Datos:
1. **Entrada**: Comandos G-Code parseados (G0, G1, G2, G3)
2. **Procesamiento**: Buffer circular con algoritmo lookahead
3. **Optimización**: Cálculo de velocidades de junta y perfiles trapezoidales
4. **Salida**: Comandos optimizados para el sistema de motion

---

## 📊 Estructuras de Datos

### planner_block_t
Representa un único movimiento en el buffer:

```c
typedef struct {
    // Identificación del movimiento
    move_type_t move_type;          // RAPID, LINEAR, ARC_CW, ARC_CCW
    
    // Geometría del movimiento
    float start_pos[3];             // [X, Y, Z] posición inicial (mm)
    float target_pos[3];            // [X, Y, Z] posición objetivo (mm)
    float distance;                 // Distancia total del movimiento (mm)
    
    // Parámetros específicos para arcos
    float arc_center[2];            // [I, J] centro del arco (solo X,Y)
    float arc_radius;               // Radio del arco (mm)
    bool arc_radius_mode;           // true=modo R, false=modo I,J
    
    // Control de velocidades
    float nominal_speed;            // Velocidad solicitada (mm/min)
    float entry_speed;              // Velocidad calculada de entrada (mm/min)
    float exit_speed;               // Velocidad calculada de salida (mm/min)
    float max_entry_speed;          // Velocidad máxima permitida en entrada
    float acceleration;             // Aceleración aplicable (mm/min²)
    
    // Flags de estado y control
    bool busy;                      // true si el bloque está en uso
    bool executed;                  // true si ya fue ejecutado
    bool recalculate_flag;          // true si necesita recálculo
    bool nominal_length_flag;       // true si puede alcanzar velocidad nominal
} planner_block_t;
```

### planner_state_t
Estado global del planner:

```c
typedef struct {
    float position[3];              // Posición actual del planner (mm)
    float previous_speed[3];        // Velocidad previa por eje
    float previous_unit_vec[3];     // Vector unitario previo
    bool is_running;                // true si está ejecutando
    bool buffer_full;               // true si el buffer está lleno
    uint32_t total_blocks_processed; // Contador de bloques procesados
} planner_state_t;
```

---

## 🌐 Variables Globales

```c
// Buffer circular principal
planner_block_t planner_buffer[PLANNER_BUFFER_SIZE];

// Índices del buffer circular
volatile uint8_t planner_buffer_head = 0;    // Índice de escritura
volatile uint8_t planner_buffer_tail = 0;    // Índice de lectura  
volatile uint8_t planner_buffer_count = 0;   // Número de bloques activos

// Estado global del sistema
planner_state_t planner_state;
```

### Gestión del Buffer Circular:
- **head**: Apunta donde se agregará el próximo bloque
- **tail**: Apunta al próximo bloque a ejecutar
- **count**: Número total de bloques pendientes
- **PLANNER_BUFFER_SIZE**: 8 bloques (configurable)

---

## 🔍 Algoritmo Lookahead

El algoritmo lookahead es el corazón del planner. Optimiza velocidades analizando múltiples movimientos futuros simultáneamente.

### Fases del Algoritmo:

#### 1. **Reverse Pass (Paso hacia Atrás)**
```c
static void planner_reverse_pass(void)
```

**Objetivo**: Propagar limitaciones de velocidad desde el final hacia el inicio del buffer.

**Lógica de Programación**:
```c
// Empezar desde el último bloque agregado
uint8_t block_index = planner_buffer_head;
if (planner_buffer_count > 0) {
    block_index = planner_prev_block_index(block_index);
}

planner_block_t *block[3] = {NULL, NULL, NULL};

// Iterar hacia atrás por el buffer
while (block_index != planner_buffer_tail) {
    // Ventana deslizante de 3 bloques
    block[2] = block[1];    // Bloque más lejano
    block[1] = block[0];    // Bloque actual
    block[0] = &planner_buffer[block_index]; // Bloque nuevo
    
    if (block[1] != NULL && block[1]->recalculate_flag) {
        // Calcular velocidad segura para la junta
        float junction_speed = 0.0f;
        
        if (block[2] != NULL) {
            junction_speed = planner_junction_velocity(block[1], block[2]);
        }
        
        // Aplicar limitación si es más restrictiva
        if (junction_speed < block[1]->exit_speed) {
            block[1]->exit_speed = junction_speed;
            block[1]->recalculate_flag = false;
        }
    }
    
    block_index = planner_prev_block_index(block_index);
}
```

**¿Por qué hacia atrás?**
- Las limitaciones de velocidad se propagan mejor desde el final
- Permite identificar restricciones que afectan bloques anteriores
- Establece velocidades de salida seguras para cada bloque

#### 2. **Forward Pass (Paso hacia Adelante)**
```c
static void planner_forward_pass(void)
```

**Objetivo**: Calcular velocidades máximas alcanzables y generar perfiles trapezoidales.

**Lógica de Programación**:
```c
uint8_t block_index = planner_buffer_tail;
planner_block_t *block[2] = {NULL, NULL};

// Iterar hacia adelante por el buffer
while (block_index != planner_buffer_head) {
    block[0] = block[1];    // Bloque anterior
    block[1] = &planner_buffer[block_index]; // Bloque actual
    
    if (block[0] != NULL) {
        // Calcular velocidad máxima físicamente alcanzable
        float max_entry_speed = planner_max_allowable_speed(
            block[1]->acceleration, 
            block[0]->exit_speed, 
            block[1]->distance
        );
        
        // Aplicar limitación física
        if (block[1]->entry_speed > max_entry_speed) {
            block[1]->entry_speed = max_entry_speed;
        }
        
        // Generar perfil trapezoidal
        float entry_factor = block[1]->entry_speed / block[1]->nominal_speed;
        float exit_factor = block[1]->exit_speed / block[1]->nominal_speed;
        planner_calculate_trapezoid(block[1], entry_factor, exit_factor);
    }
    
    block_index = planner_next_block_index(block_index);
}
```

**¿Por qué hacia adelante?**
- Las limitaciones físicas se propagan mejor desde el inicio
- Permite calcular qué velocidad es realmente alcanzable
- Genera los perfiles de velocidad finales

---

## 🔧 Funciones Públicas

### void planner_init(void)

**Propósito**: Inicializar completamente el sistema del planner.

**Lógica de Programación**:
```c
void planner_init(void) {
    // 1. Limpiar buffer completamente
    memset(planner_buffer, 0, sizeof(planner_buffer));
    
    // 2. Resetear índices del buffer circular
    planner_buffer_head = 0;
    planner_buffer_tail = 0;
    planner_buffer_count = 0;
    
    // 3. Inicializar estado del planner
    memset(&planner_state, 0, sizeof(planner_state));
    planner_state.is_running = false;
    planner_state.buffer_full = false;
    planner_state.total_blocks_processed = 0;
    
    // 4. Sincronizar con la posición actual del hardware
    float current_pos[3];
    getCurrentPositionMM(&current_pos[0], &current_pos[1], &current_pos[2]);
    planner_set_current_position(current_pos);
}
```

**Consideraciones**:
- Sincronización con hardware es crítica
- Buffer debe estar completamente limpio
- Estado debe ser consistente

### bool planner_buffer_line(float target[3], float feed_rate, bool is_rapid)

**Propósito**: Agregar un movimiento lineal (G0/G1) al buffer del planner.

**Lógica de Programación**:
```c
bool planner_buffer_line(float target[3], float feed_rate, bool is_rapid) {
    // 1. Verificar disponibilidad de espacio
    if (planner_buffer_count >= PLANNER_BUFFER_SIZE) {
        planner_state.buffer_full = true;
        return false; // Buffer lleno, no se puede agregar
    }
    
    // 2. Obtener bloque libre en la cabeza del buffer
    planner_block_t *block = &planner_buffer[planner_buffer_head];
    
    // 3. Configurar tipo de movimiento
    block->move_type = is_rapid ? MOVE_TYPE_RAPID : MOVE_TYPE_LINEAR;
    
    // 4. Establecer geometría del movimiento
    memcpy(block->start_pos, planner_state.position, sizeof(float) * 3);
    memcpy(block->target_pos, target, sizeof(float) * 3);
    
    // 5. Calcular distancia euclidiana
    block->distance = planner_calculate_distance(block->start_pos, block->target_pos);
    
    // 6. Filtrar movimientos microscópicos
    if (block->distance < 0.001f) {
        return true; // Movimiento válido pero ignorado
    }
    
    // 7. Configurar parámetros de velocidad
    block->nominal_speed = is_rapid ? rapidRate : feed_rate;
    if (block->nominal_speed > maxFeedRate) {
        block->nominal_speed = maxFeedRate; // Aplicar límite global
    }
    
    // 8. Configurar parámetros de aceleración
    block->acceleration = ACCELERATION;
    
    // 9. Inicializar velocidades para lookahead
    block->entry_speed = 0.0f;
    block->exit_speed = 0.0f;
    block->max_entry_speed = block->nominal_speed;
    
    // 10. Establecer flags de control
    block->busy = true;
    block->executed = false;
    block->recalculate_flag = true;
    block->nominal_length_flag = true;
    
    // 11. Actualizar posición interna del planner
    memcpy(planner_state.position, target, sizeof(float) * 3);
    
    // 12. Avanzar índices del buffer circular
    planner_buffer_head = planner_next_block_index(planner_buffer_head);
    planner_buffer_count++;
    
    // 13. Ejecutar optimización lookahead
    planner_recalculate();
    
    return true;
}
```

**Consideraciones Clave**:
- **Filtro de distancia**: Evita movimientos microscópicos que pueden causar problemas
- **Limitación de velocidad**: Siempre respeta el máximo global del sistema
- **Sincronización de posición**: El planner mantiene su propia copia de la posición
- **Trigger de optimización**: Cada nuevo bloque desencadena recálculo lookahead

### bool planner_buffer_arc(float target[3], float offset[2], bool is_clockwise, bool is_radius_mode, float feed_rate)

**Propósito**: Agregar un movimiento de arco (G2/G3) al buffer del planner.

**Lógica de Programación**:

#### Fase 1: Validación y Configuración Inicial
```c
// Verificar espacio en buffer
if (planner_buffer_count >= PLANNER_BUFFER_SIZE) {
    planner_state.buffer_full = true;
    return false;
}

// Obtener bloque y configurar tipo
planner_block_t *block = &planner_buffer[planner_buffer_head];
block->move_type = is_clockwise ? MOVE_TYPE_ARC_CW : MOVE_TYPE_ARC_CCW;

// Establecer posiciones
memcpy(block->start_pos, planner_state.position, sizeof(float) * 3);
memcpy(block->target_pos, target, sizeof(float) * 3);
```

#### Fase 2: Cálculo del Centro del Arco

**Modo R (Radio):**
```c
if (is_radius_mode) {
    block->arc_radius = offset[0];
    
    // Calcular geometría del arco usando radio
    float dx = block->target_pos[0] - block->start_pos[0];
    float dy = block->target_pos[1] - block->start_pos[1];
    float chord_distance = sqrtf(dx*dx + dy*dy);
    
    // Validar que el radio sea físicamente posible
    if (block->arc_radius < chord_distance / 2.0f) {
        return false; // Geometría imposible
    }
    
    // Calcular altura del triángulo usando Pitágoras
    float h = sqrtf(block->arc_radius * block->arc_radius - 
                   (chord_distance / 2.0f) * (chord_distance / 2.0f));
    
    // Punto medio de la cuerda
    float mid_x = (block->start_pos[0] + block->target_pos[0]) / 2.0f;
    float mid_y = (block->start_pos[1] + block->target_pos[1]) / 2.0f;
    
    // Vector perpendicular unitario
    float perp_x = -dy / chord_distance;
    float perp_y = dx / chord_distance;
    
    // Determinar lado del centro basado en dirección y signo
    float sign = (is_clockwise == (block->arc_radius > 0)) ? -1.0f : 1.0f;
    block->arc_center[0] = mid_x + sign * h * perp_x;
    block->arc_center[1] = mid_y + sign * h * perp_y;
    
    block->arc_radius = fabsf(block->arc_radius);
}
```

**Modo I,J (Offset):**
```c
else {
    // Centro relativo a posición inicial
    block->arc_center[0] = block->start_pos[0] + offset[0];
    block->arc_center[1] = block->start_pos[1] + offset[1];
    
    // Calcular radio desde el centro
    float dx_start = block->start_pos[0] - block->arc_center[0];
    float dy_start = block->start_pos[1] - block->arc_center[1];
    block->arc_radius = sqrtf(dx_start*dx_start + dy_start*dy_start);
}
```

#### Fase 3: Cálculo de la Longitud del Arco
```c
// Calcular ángulos de inicio y fin
float dx_start = block->start_pos[0] - block->arc_center[0];
float dy_start = block->start_pos[1] - block->arc_center[1];
float dx_end = block->target_pos[0] - block->arc_center[0];
float dy_end = block->target_pos[1] - block->arc_center[1];

float start_angle = atan2f(dy_start, dx_start);
float end_angle = atan2f(dy_end, dx_end);

float angular_travel = end_angle - start_angle;

// Ajustar ángulo según dirección del arco
if (is_clockwise) {
    if (angular_travel >= 0) {
        angular_travel -= 2.0f * PI; // Forzar negativo para CW
    }
} else {
    if (angular_travel <= 0) {
        angular_travel += 2.0f * PI; // Forzar positivo para CCW
    }
}

// Calcular longitud del arco: s = rθ
block->distance = fabsf(angular_travel) * block->arc_radius;

// Incluir componente Z si existe (arco helicoidal)
float dz = block->target_pos[2] - block->start_pos[2];
if (fabsf(dz) > 0.001f) {
    float linear_distance = sqrtf(block->distance * block->distance + dz * dz);
    block->distance = linear_distance;
}
```

**Consideraciones Matemáticas**:
- **atan2f()**: Maneja correctamente todos los cuadrantes
- **Dirección del arco**: Crucial para determinar el recorrido angular
- **Arcos helicoidales**: Combinación de movimiento circular y lineal en Z

### bool planner_process_next_block(void)

**Propósito**: Procesar y ejecutar el siguiente bloque del buffer.

**Lógica de Programación**:
```c
bool planner_process_next_block(void) {
    // 1. Verificar si hay trabajo pendiente
    if (planner_buffer_count == 0) {
        planner_state.is_running = false;
        return false; // Buffer vacío
    }
    
    // 2. Obtener siguiente bloque a ejecutar
    planner_block_t *block = &planner_buffer[planner_buffer_tail];
    
    // 3. Verificar estado del bloque
    if (!block->busy || block->executed) {
        return false; // Bloque no válido para ejecución
    }
    
    // 4. Marcar planner como activo
    planner_state.is_running = true;
    
    // 5. Ejecutar el bloque
    bool success = planner_execute_block(block);
    
    if (success) {
        // 6. Actualizar estado del bloque
        block->executed = true;
        block->busy = false;
        
        // 7. Avanzar cola del buffer
        planner_buffer_tail = planner_next_block_index(planner_buffer_tail);
        planner_buffer_count--;
        planner_state.total_blocks_processed++;
        
        // 8. Resetear flag de buffer lleno
        planner_state.buffer_full = false;
    }
    
    return success;
}
```

---

## 🔐 Funciones Privadas
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

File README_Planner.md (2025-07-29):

# Ejemplo de uso del Planner Lookahead

Este documento explica cómo usar el nuevo módulo de planner lookahead implementado.

## Características del Planner

- **Buffer de 8 líneas**: Planifica hasta 8 comandos G-code por adelantado
- **Optimización de velocidades**: Calcula velocidades óptimas en las juntas entre movimientos
- **Soporte completo**: G0 (rápido), G1 (lineal), G2 (arco CW), G3 (arco CCW)
- **Configuración de arcos**: Soporta modo R (radio) para G2/G3
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

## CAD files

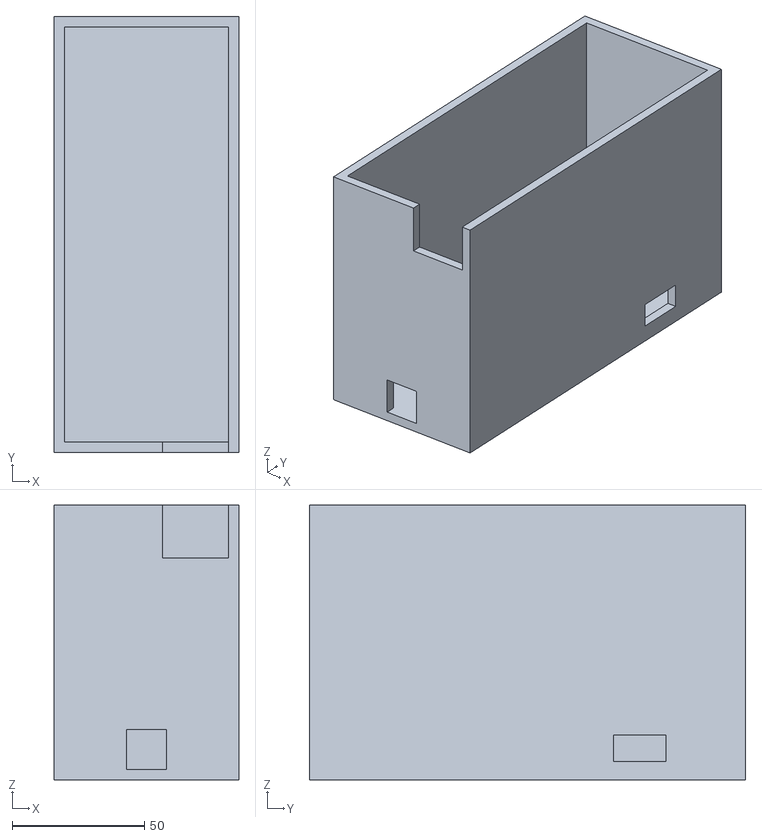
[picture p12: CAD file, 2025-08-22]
3D_FILES/case.stl
70.0 x 165.0 x 104.0

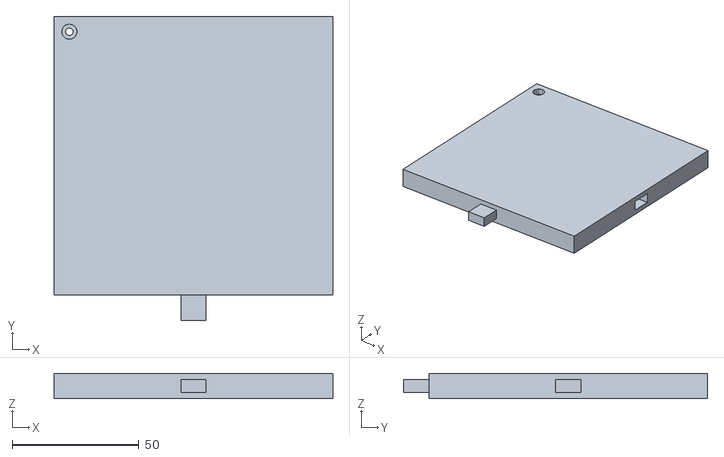
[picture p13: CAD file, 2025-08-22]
3D_FILES/Case bluepill - ramp.stl
110.0 x 120.0 x 10.0

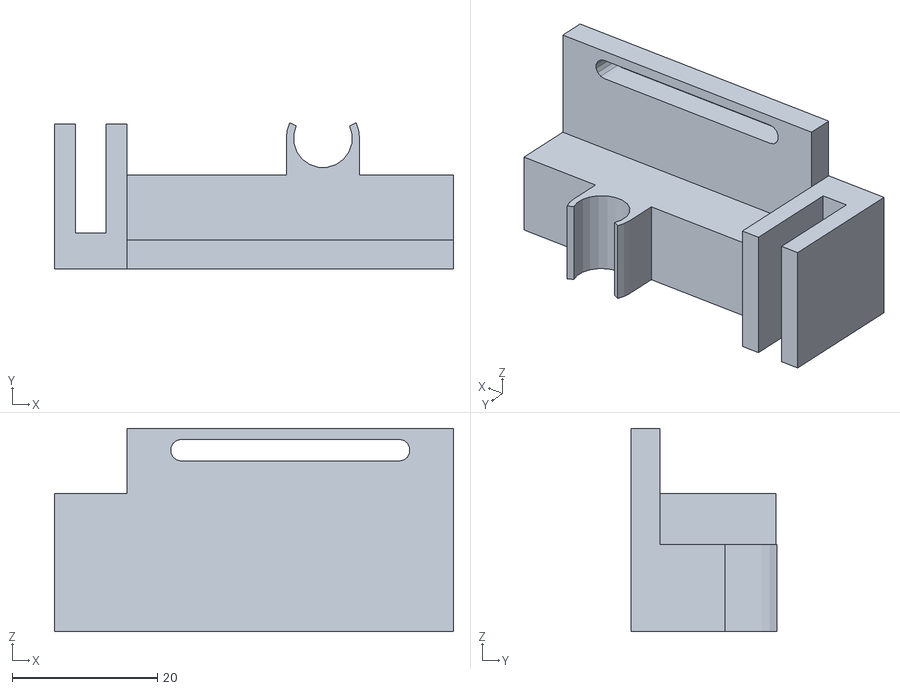
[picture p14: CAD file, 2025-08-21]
3D_FILES/fin_de_carrera_eje_z.stl
55.0 x 20.2 x 28.0

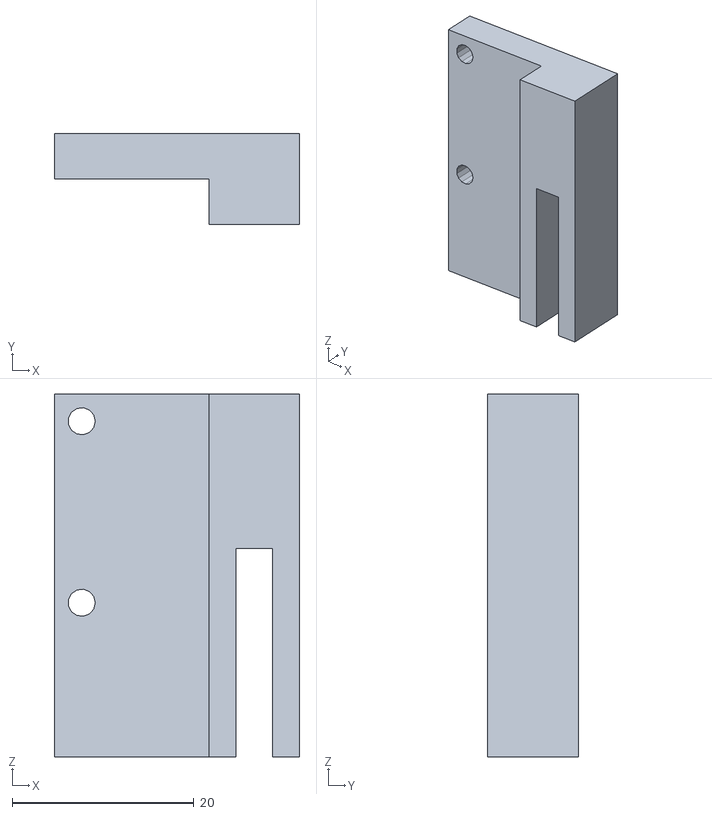
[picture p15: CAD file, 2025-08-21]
3D_FILES/fin_de_carrera_eje_y.stl
27.0 x 10.0 x 40.0

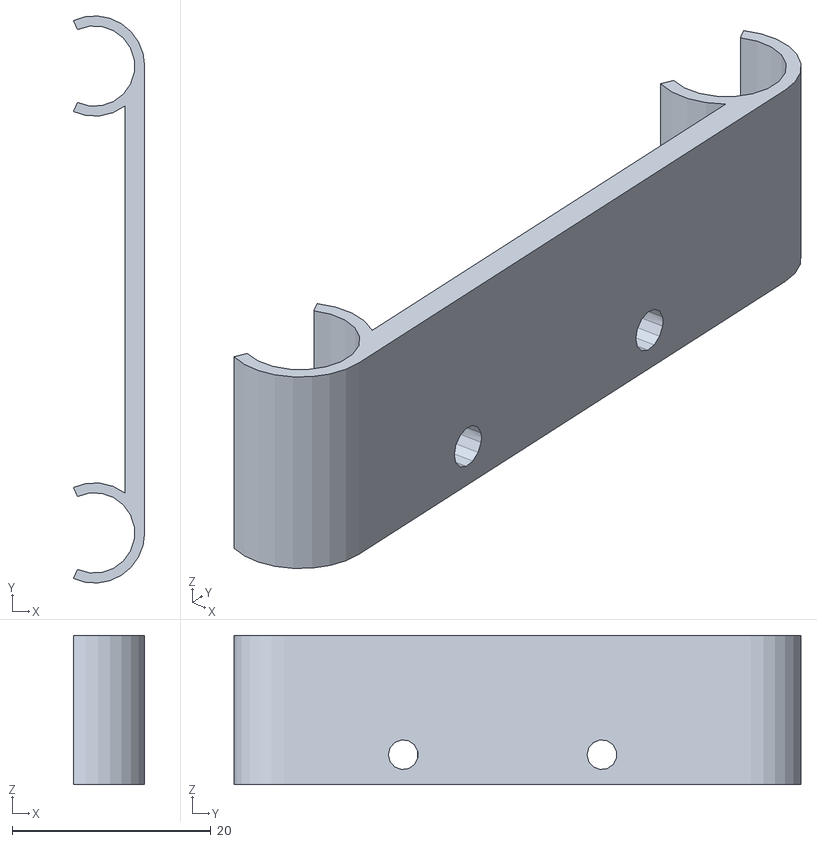
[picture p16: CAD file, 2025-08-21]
3D_FILES/fin_de_carrera_eje_x.stl
7.18 x 57.1 x 15.0

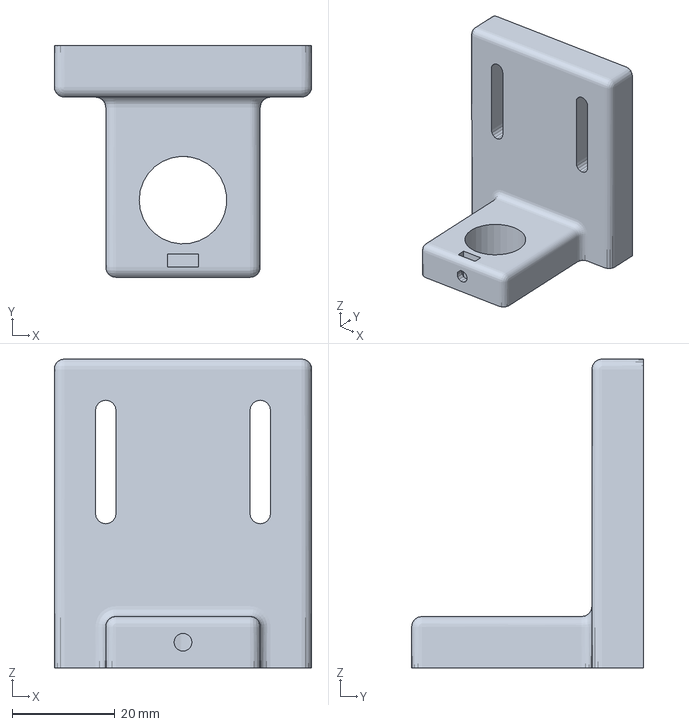
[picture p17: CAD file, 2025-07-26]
3D_FILES/soporte eje x.3mf
50.0 x 45.0 x 60.0 mm

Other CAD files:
3D_FILES/soporte eje x.stl

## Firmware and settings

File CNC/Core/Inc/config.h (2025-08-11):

/*
  config.h - Configuraciones del CNC Controller
  
  Este archivo contiene todas las definiciones y configuraciones
  principales del sistema CNC.
*/

#ifndef CONFIG_H
#define CONFIG_H

// ===========================================================================================
// CONFIGURACIÓN DE DEBUG
// ===========================================================================================
#define DEBUG_MESSAGES 0  // Cambiar a 0 para desactivar mensajes de debug

// ===========================================================================================
// CONFIGURACIÓN DE MOTORES Y MOVIMIENTO
// ===========================================================================================

// Configuración real de la máquina (valores calibrados)
#define STEPS_PER_MM_X 79      // Pasos por mm para eje X
#define STEPS_PER_MM_Y 79      // Pasos por mm para eje Y
#define STEPS_PER_MM_Z 3930    // Pasos por mm para eje Z

// Timing para motores paso a paso
#define STEP_DELAY_US 800      // Delay entre pulsos de paso en microsegundos

// ===========================================================================================
// CONFIGURACIÓN DE LÍMITES DE LA MÁQUINA
// ===========================================================================================

// Límites de trabajo de la máquina (en mm)
#define MAX_TRAVEL_X 160.0f    // Recorrido máximo eje X (mm)
#define MAX_TRAVEL_Y 160.0f    // Recorrido máximo eje Y (mm)  
#define MAX_TRAVEL_Z 160.0f    // Recorrido máximo eje Z (mm)

// Límites mínimos (origen)
#define MIN_TRAVEL_X 0.0f      // Límite mínimo eje X (mm)
#define MIN_TRAVEL_Y 0.0f      // Límite mínimo eje Y (mm)
#define MIN_TRAVEL_Z 0.0f      // Límite mínimo eje Z (mm)

// Margen de seguridad para los límites
#define SAFETY_MARGIN 2.0f     // Margen de seguridad en mm

// ===========================================================================================
// CONFIGURACIÓN DE ARCOS Y CÍRCULOS
// ===========================================================================================

// Definiciones de segmentos para arcos
#define SEGMENTS 50
#define PI 3.14159265358979323846


// ===========================================================================================
// CONFIGURACIÓN DE PINES STM32F103C8T6 (Blue Pill)
// ===========================================================================================

// Definiciones de pines para motores paso a paso - Eje X
#define X_STEP_PIN    GPIO_PIN_6   // PB6
#define X_DIR_PIN     GPIO_PIN_7   // PB7
#define X_EN_PIN      GPIO_PIN_8   // PA8
#define X_MIN_PIN     GPIO_PIN_12  // PB12

// Definiciones de pines para motores paso a paso - Eje Y
#define Y_STEP_PIN    GPIO_PIN_9   // PB9
#define Y_DIR_PIN     GPIO_PIN_3   // PB3
#define Y_EN_PIN      GPIO_PIN_4   // PB4
#define Y_MIN_PIN     GPIO_PIN_13  // PB13

// Definiciones de pines para motores paso a paso - Eje Z
#define Z_STEP_PIN    GPIO_PIN_8   // PA8
#define Z_DIR_PIN     GPIO_PIN_9   // PA9
#define Z_EN_PIN      GPIO_PIN_10  // PA10
#define Z_MIN_PIN     GPIO_PIN_14  // PB14

// LEDs indicadores
#define LED_ERROR     GPIO_PIN_0   // PB0
#define LED_CHECK     GPIO_PIN_1   // PB1

// ===========================================================================================
// CONFIGURACIÓN DE VELOCIDADES POR DEFECTO
// ===========================================================================================

// Velocidades por defecto (en mm/min)
#define DEFAULT_FEED_RATE 100.0f     // Feed rate por defecto
#define DEFAULT_RAPID_RATE 1000.0f   // Velocidad rápida para G0
#define DEFAULT_MAX_FEED_RATE 2000.0f // Velocidad máxima permitida

// ===========================================================================================
// CONFIGURACIÓN DE BUFFERS
// ===========================================================================================

// Buffer para mensajes de salida
#define OUTPUT_BUFFER_SIZE 950

// Buffer para comandos USB CDC
#define USB_BUFFER_SIZE 100

// Buffer para almacenar programa G-code
#define MAX_GCODE_LINES 100    // Máximo número de líneas de G-code a almacenar
#define MAX_LINE_LENGTH 80     // Longitud máxima de cada línea de G-code

// ===========================================================================================
// CONFIGURACIÓN DE COMUNICACIÓN USB CDC
// ===========================================================================================

// Método de transmisión USB CDC (puedes cambiar esto según tus necesidades)
typedef enum {
    USB_METHOD_DIRECT,      // Envío directo (puede perderse si está ocupado)
    USB_METHOD_RETRY,       // Envío con reintentos (bloquea hasta enviar)
    USB_METHOD_QUEUED       // Envío mediante cola (recomendado)
} USBTransmitMethod_t;

#define USB_TRANSMIT_METHOD USB_METHOD_QUEUED  // ← Cambiar aquí el método

#endif // CONFIG_H

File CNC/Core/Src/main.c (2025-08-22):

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
/* Includes ------------------------------------------------------------------*/
#include "main.h"
#include "usb_device.h"

/* USER CODE BEGIN Includes */
#include <string.h>
#include <stdio.h>
#include <stdlib.h>
#include <stdbool.h>
#include <math.h>
#include <stdint.h>
#include "usbd_cdc_if.h"
#include "stm32f1xx_hal.h"
#include "gcode_parser.h"
#include "config.h"
#include "motion.h"
//#include "usart.h"
/* USER CODE END Includes */

/* USER CODE BEGIN PD */

// Función auxiliar para envío USB según el método configurado
void sendUSBText(const char* message) {
    //uint16_t len = strlen(message);
    //CDC_Transmit_Queued((uint8_t*)message, len);
    HAL_UART_Transmit(&huart2, (uint8_t*)message, strlen(message), HAL_MAX_DELAY);
}

/* USER CODE END PD */

UART_HandleTypeDef huart2;

/* USER CODE BEGIN PV */
extern UART_HandleTypeDef huart1;
// Declarar buffer global (accesible desde motion.c)
char outputBuffer[OUTPUT_BUFFER_SIZE];
int bufferIndex = 0;
bool commandComplete = false;
int32_t currentX, currentY, currentZ;

// Variables para control de velocidad y feed rate
float currentFeedRate = DEFAULT_FEED_RATE;     // Feed rate en mm/min (valor por defecto)
float rapidRate = DEFAULT_RAPID_RATE;          // Velocidad rápida para G0 en mm/min
float maxFeedRate = DEFAULT_MAX_FEED_RATE;     // Velocidad máxima permitida

// Buffer para recibir comandos por USB CDC
char usbBuffer[USB_BUFFER_SIZE];
int usbBufferIndex = 0;
bool usbCommandComplete = false;  // Cambiar a false para evitar procesamiento inicial

// Sistema de almacenamiento de programa G-code
char gcodeProgram[MAX_GCODE_LINES][MAX_LINE_LENGTH];  // Buffer para almacenar el programa
int programLineCount = 0;          // Número de líneas actualmente almacenadas
int currentExecutingLine = 0;      // Línea que se está ejecutando actualmente
bool isStoringProgram = false;     // Flag para indicar si estamos en modo almacenamiento
bool isProgramLoaded = false;      // Flag para indicar si hay un programa cargado
bool isProgramRunning = false;     // Flag para indicar si el programa se está ejecutando


/* USER CODE END PV */

void SystemClock_Config(void);
static void MX_GPIO_Init(void);
static void MX_USART2_UART_Init(void);
/* USER CODE BEGIN PFP */
void loop(void);
void setup(void);
// void moveAxes(float x, float y, float z);
void processGcode(const char* command);
void performHoming(void);
bool isEndstopPressed(char axis);
void showConfiguration(void);
void report_status_message(uint8_t status_code);
void endstop_error_handler(char axis);

// Funciones para manejo de programa G-code
void startProgramStorage(void);
void stopProgramStorage(void);
bool addLineToProgram(const char* line);
void clearProgram(void);
void runProgram(void);
void runNextLine(void);
void pauseProgram(void);
void stopProgram(void);
void showHelp(void);
void showQueueStatus(void);  // Nueva función de diagnóstico
void showProgramStatus(void); // Nueva función para estado del programa


void processProgram(void);  // Nueva función para ejecutar programa progresivamente


/* USER CODE END PFP */

/**
  * @brief  The application entry point.
  * @retval int
  */
int main(void)
{

  /* MCU Configuration--------------------------------------------------------*/

  /* Reset of all peripherals, Initializes the Flash interface and the Systick. */
  HAL_Init();

  /* Configure the system clock */
  SystemClock_Config();

  /* USER CODE BEGIN SysInit */

    // Inicializar cola de transmisión USB CDC
    CDC_TxQueue_Init();

    // Inicialización similar al setup() de Arduino
    setup();



    #if DEBUG_MESSAGES
    // Mensaje adicional de debug
    CDC_Transmit_Queued((uint8_t*)"Sistema iniciado - Esperando comandos...\r\n", 42);
    #endif
  /* USER CODE END SysInit */

  /* Initialize all configured peripherals */
  MX_GPIO_Init();
  MX_USART2_UART_Init();
  MX_USB_DEVICE_Init();
  /* USER CODE BEGIN 2 */
    // Led de encendido inicial
    HAL_GPIO_WritePin(GPIOB, LED_CHECK, GPIO_PIN_SET);  // Encender
    // Envío inicial usando cola
    CDC_Transmit_Queued((uint8_t*)"G-code listo\r\n", 14); 
    
  /* USER CODE END 2 */

  /* Infinite loop */
  /* USER CODE BEGIN WHILE */
  while (1)
  {
    // Procesar cola de transmisión USB CDC
    CDC_TxQueue_Process();
    
    loop();
    
    /* USER CODE END WHILE */

    /* USER CODE BEGIN 3 */
  }
  /* USER CODE END 3 */
}

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
/* USER CODE BEGIN 4 */
void processGcode(const char* command) {
    // Comandos especiales para control de programa
    if (strncmp(command, "PROGRAM_START", 13) == 0) {
        startProgramStorage();
        return;
    }
    else if (strncmp(command, "PROGRAM_STOP", 12) == 0) {
        stopProgramStorage();
        return;
    }
    else if (strncmp(command, "PROGRAM_RUN", 11) == 0) {
        runProgram();
        return;
    }
    else if (strncmp(command, "PROGRAM_CLEAR", 13) == 0) {
        clearProgram();
        return;
    }
    else if (strncmp(command, "PROGRAM_PAUSE", 13) == 0) {
        pauseProgram();
        return;
    }
    else if (strncmp(command, "PROGRAM_NEXT", 12) == 0) {
        runNextLine();
        return;
    }
    else if (strncmp(command, "PROGRAM_STATUS", 14) == 0) {
        showProgramStatus();
        return;
    }
    else if (strncmp(command, "HELP", 4) == 0 || strncmp(command, "help", 4) == 0) {
        showHelp();
        return;
    }
    else if (strncmp(command, "QUEUE_STATUS", 12) == 0) {
        showQueueStatus();
        return;
    }
    else if (strncmp(command, "FIN", 3) == 0 || strncmp(command, "fin", 3) == 0) {
        if (isStoringProgram) {
            stopProgramStorage();
            return;
        }
    }    
    // Si estamos en modo almacenamiento, agregar la línea al programa
    if (isStoringProgram) {
        if (addLineToProgram(command)) {
            sendUSBText("ok\r\n");
        } else {
            // El error ya fue enviado por addLineToProgram
            // Detener el modo de almacenamiento
            isStoringProgram = false;
            isProgramLoaded = false;
            programLineCount = 0;
        }
        return;
    }
    
    // Procesamiento normal de G-code
    char line_copy[100];
    strncpy(line_copy, command, sizeof(line_copy) - 1);
    line_copy[sizeof(line_copy) - 1] = '\0';
    
    uint8_t status = gc_execute_line(line_copy);
    
    
    // Enviar respuesta final usando el parser modular
    report_status_message(status);
}

void loop(void) {
    #if DEBUG_MESSAGES
    // Heartbeat para confirmar que el sistema está funcionando
    static uint32_t lastHeartbeat = 0;
    uint32_t currentTime = HAL_GetTick();  // Declarar currentTime
    
    // Debug: mostrar tiempo actual
    char debugMsg[50];
    sprintf(debugMsg, "[DEBUG] Tiempo actual: %lu\r\n", currentTime);
    sendUSBText(debugMsg);
    

    // Heartbeat cada 5 segundos para confirmar que está vivo
    if (currentTime - lastHeartbeat > 5000) {
        lastHeartbeat = currentTime;
        sendUSBText("[HEARTBEAT] Sistema activo\r\n");
    }
    #endif
    
    
    // Procesar programa en ejecución (si corresponde)
    if (isProgramRunning) {
        processProgram();
    }
    
    // Procesar comandos USB CDC - SOLO cuando hay un comando completo
    if (usbCommandComplete) {
        #if DEBUG_MESSAGES
        // Debug: mostrar estado de variables
        char debugStatus[200];  // Buffer más grande para evitar overflow
        sprintf(debugStatus, "[DEBUG] usbCommandComplete=true, bufferIndex=%d, buffer=[%s]\r\n", 
                usbBufferIndex, usbBuffer);
        sendUSBText(debugStatus);
        #endif
        
        // Verificar que el buffer no esté vacío y contenga algo más que espacios
        bool hasValidCommand = false;
        for (int i = 0; i < usbBufferIndex; i++) {
            if (usbBuffer[i] != ' ' && usbBuffer[i] != '\t' && usbBuffer[i] != '\r' && usbBuffer[i] != '\n') {
                hasValidCommand = true;
                break;
            }
        }
        
        if (hasValidCommand && usbBufferIndex > 0) {
            #if DEBUG_MESSAGES
            // Debug: confirmar que llegó el comando (buffer más grande para evitar warning)
            sprintf(outputBuffer, ">>> [%s]\r\n", usbBuffer);
            sendUSBText(outputBuffer);
            
            #endif
            
            processGcode(usbBuffer);
        }
        
        // IMPORTANTE: Resetear todo después de procesar (o intentar procesar)
        usbBufferIndex = 0;
        memset(usbBuffer, 0, sizeof(usbBuffer));
        usbCommandComplete = false;  // Asegurar que se resetee correctamente
    }
}

void setup(void) {
    // Activar DWT para microsegundos
    CoreDebug->DEMCR |= CoreDebug_DEMCR_TRCENA_Msk;
    DWT->CTRL |= DWT_CTRL_CYCCNTENA_Msk;
    
    // Habilitar drivers de motores (EN pins en LOW)
    enableSteppers();

    // Asegurar que LEDs estén apagados al inicio
    HAL_GPIO_WritePin(GPIOB, LED_CHECK, GPIO_PIN_RESET);
    HAL_GPIO_WritePin(GPIOB, LED_ERROR, GPIO_PIN_RESET);

    // Secuencia de 3 parpadeos de los LEDs de chequeo y error
    for (int i = 0; i < 3; i++) {
        HAL_GPIO_WritePin(GPIOB, LED_CHECK, GPIO_PIN_SET);
        HAL_GPIO_WritePin(GPIOB, LED_ERROR, GPIO_PIN_SET);
        HAL_Delay(150);
        HAL_GPIO_WritePin(GPIOB, LED_CHECK, GPIO_PIN_RESET);
        HAL_GPIO_WritePin(GPIOB, LED_ERROR, GPIO_PIN_RESET);
        HAL_Delay(150);
    }
    
    // Inicializar parser G-code modular con callbacks
    gc_init();
    
}



// Callback específico para movimiento rápido G0
void moveAxesRapidCallback(float x, float y, float z, bool x_defined, bool y_defined, bool z_defined) {
    // Usar movimiento directo (modo compatibilidad)
    float target_x = x_defined ? x : NAN;
    float target_y = y_defined ? y : NAN;
    float target_z = z_defined ? z : NAN;
    
    moveAxesWithFeedRate(target_x, target_y, target_z, rapidRate, true);
}

void moveAxesArcCallback(float x, float y, float r, bool clockwise, float feedRate, bool f_defined) {
    // Actualizar feed rate actual si se especifica
    if (f_defined && feedRate > 0) {
        currentFeedRate = feedRate;
    }
    
    // Usar movimiento directo con feed rate actual
    arc_move_r(x, y, r, clockwise, currentFeedRate);
}

// Callback específico para movimiento lineal G1 con feed rate 
void moveAxesLinearCallback(float x, float y, float z, float feedRate, bool x_defined, bool y_defined, bool z_defined, bool f_defined) {
    // Actualizar feed rate actual si se especifica
    if (f_defined && feedRate > 0) {
        currentFeedRate = feedRate;
    }
    
    float target_x = x_defined ? x : NAN;
    float target_y = y_defined ? y : NAN;
    float target_z = z_defined ? z : NAN;
    
    moveAxesWithFeedRate(target_x, target_y, target_z, currentFeedRate, false);
}

// Función para mostrar la configuración actual del sistema
void showConfiguration(void) {
    
    sendUSBText("=== CONFIGURACIÓN CNC ===\r\n");

    sprintf(outputBuffer, "Steps per mm X: %d\r\n", STEPS_PER_MM_X);
    sendUSBText(outputBuffer);
    

    sprintf(outputBuffer, "Steps per mm Y: %d\r\n", STEPS_PER_MM_Y);
    sendUSBText(outputBuffer);
    

    sprintf(outputBuffer, "Steps per mm Z: %d\r\n", STEPS_PER_MM_Z);
    sendUSBText(outputBuffer);
    

    sprintf(outputBuffer, "Step delay: %d us\r\n", STEP_DELAY_US);
    sendUSBText(outputBuffer);
    
    
    // Convertir feed rate actual a enteros
    int feed_int = (int)currentFeedRate;
    int feed_dec = (int)((currentFeedRate - feed_int) * 10);
    sprintf(outputBuffer, "Feed rate actual: %d.%d mm/min\r\n", feed_int, feed_dec);
    sendUSBText(outputBuffer);
    

    // Convertir velocidades a enteros para mostrar
    int rapid_int = (int)rapidRate;
    int rapid_dec = (int)((rapidRate - rapid_int) * 10);
    sprintf(outputBuffer, "Velocidad rápida (G0): %d.%d mm/min\r\n", rapid_int, rapid_dec);
    sendUSBText(outputBuffer);
    
    
    int max_int = (int)maxFeedRate;
    int max_dec = (int)((maxFeedRate - max_int) * 10);
    sprintf(outputBuffer, "Velocidad máxima: %d.%d mm/min\r\n", max_int, max_dec);
    sendUSBText(outputBuffer);
    

    // Mostrar posición actual
    float xPos = currentX / (float)STEPS_PER_MM_X;
    float yPos = currentY / (float)STEPS_PER_MM_Y;
    float zPos = currentZ / (float)STEPS_PER_MM_Z;
    
    // Convertir a enteros para evitar problemas con printf float
    int x_int = (int)xPos;
    int x_dec = (int)((xPos - x_int) * 100);
    int y_int = (int)yPos;
    int y_dec = (int)((yPos - y_int) * 100);
    int z_int = (int)zPos;
    int z_dec = (int)((zPos - z_int) * 100);

    sprintf(outputBuffer, "Posición actual: X%d.%02d Y%d.%02d Z%d.%02d mm\r\n",
           x_int, abs(x_dec), y_int, abs(y_dec), z_int, abs(z_dec));
    sendUSBText(outputBuffer);
    
    sendUSBText("=== FIN CONFIGURACIÓN ===\r\n");
}

// Función para verificar si un final de carrera está presionado
bool isEndstopPressed(char axis) {
    switch(axis) {
        case 'X':
            return (HAL_GPIO_ReadPin(GPIOB, X_MIN_PIN) == GPIO_PIN_RESET);
        case 'Y':
            return (HAL_GPIO_ReadPin(GPIOB, Y_MIN_PIN) == GPIO_PIN_RESET);
        case 'Z':
            return (HAL_GPIO_ReadPin(GPIOB, Z_MIN_PIN) == GPIO_PIN_RESET);
        default:
            return false;
    }
}

// Función de homing para todos los ejes
void performHoming(void) {
    HAL_NVIC_DisableIRQ(EXTI15_10_IRQn);
    
    // Enviar mensaje de inicio de homing
    sendUSBText("Iniciando secuencia de homing...\r\n");
    
    // FASE 1: Movimiento rápido hacia los finales de carrera
    sprintf(outputBuffer, "Fase 1: Buscando finales de carrera...\r\n");
    sendUSBText(outputBuffer);
    

    // Homing del eje X
    sprintf(outputBuffer, "Homing eje X...\r\n");
    sendUSBText(outputBuffer);
    

    // Mover hacia el final de carrera X (dirección negativa)
    HAL_GPIO_WritePin(GPIOB, X_DIR_PIN, GPIO_PIN_RESET); // Dirección negativa
    while (!isEndstopPressed('X')) {
        X_stepOnce();
        delay_us(STEP_DELAY_US);
    }
    
    // FASE 1: Retroceder 2mm del final de carrera X
    HAL_GPIO_WritePin(GPIOB, X_DIR_PIN, GPIO_PIN_SET); // Dirección positiva
    for (int i = 0; i < 4*STEPS_PER_MM_X; i++) { // Exactamente 2mm
        X_stepOnce();
        delay_us(STEP_DELAY_US);
    }
    
    // Verificar que se liberó el switch después de alejarse 2mm
    if (isEndstopPressed('X')) {
        sprintf(outputBuffer, "Error: Fin de carrera X no se liberó después de alejarse 2mm\r\n");
        sendUSBText(outputBuffer);
        
        return;
    }
    

    
    // FASE 2: Regresar 4mm hacia el final de carrera X
    HAL_GPIO_WritePin(GPIOB, X_DIR_PIN, GPIO_PIN_RESET); // Dirección negativa
    for (int i = 0; i < 4*STEPS_PER_MM_X; i++) { // Exactamente 4mm de regreso
        X_stepOnce();
        delay_us(STEP_DELAY_US *3); // Movimiento lento para precisión
    }
    // Pausa para estabilización
    HAL_Delay(100);
    // Verificar que el final de carrera esté presionado después de regresar 4mm
    if (!isEndstopPressed('X')) {
        sprintf(outputBuffer, "Error: Fin de carrera X no está presionado después de regresar 4mm\r\n");
        sendUSBText(outputBuffer);
        
        return;
    }
    currentX = 0; // Establecer posición home
    sprintf(outputBuffer, "Eje X en posición home\r\n");
    sendUSBText(outputBuffer);
    


    // Homing del eje Y
    sprintf(outputBuffer, "Homing eje Y...\r\n");
    sendUSBText(outputBuffer);
    

    // Mover hacia el final de carrera Y (dirección negativa)
    HAL_GPIO_WritePin(GPIOB, Y_DIR_PIN, GPIO_PIN_RESET); // Dirección negativa
    while (!isEndstopPressed('Y')) {
        Y_stepOnce();
        delay_us(STEP_DELAY_US);
    }
    
    // FASE 1: Retroceder 4mm del final de carrera Y
    HAL_GPIO_WritePin(GPIOB, Y_DIR_PIN, GPIO_PIN_SET); // Dirección positiva
    for (int i = 0; i < 4*STEPS_PER_MM_Y; i++) { // Exactamente 4mm
        Y_stepOnce();
        delay_us(STEP_DELAY_US);
    }
    
    // Verificar que se liberó el switch después de alejarse 4mm
    if (isEndstopPressed('Y')) {
        sprintf(outputBuffer, "Error: Fin de carrera Y no se liberó después de alejarse 4mm\r\n");
        sendUSBText(outputBuffer);
        
        return;
    }
    

    
    // FASE 2: Regresar 4mm hacia el final de carrera Y
    HAL_GPIO_WritePin(GPIOB, Y_DIR_PIN, GPIO_PIN_RESET); // Dirección negativa
    for (int i = 0; i < 4.02*STEPS_PER_MM_Y; i++) { // Exactamente 4mm de regreso
        Y_stepOnce();
        delay_us(STEP_DELAY_US*3); // Movimiento lento para precisión
    }
    // Pausa para estabilización
    HAL_Delay(100);
    // Verificar que el final de carrera esté presionado después de regresar 4mm
    if (!isEndstopPressed('Y')) {
        sprintf(outputBuffer, "Error: Fin de carrera Y no está presionado después de regresar 4mm\r\n");
        sendUSBText(outputBuffer);
        
        return;
    }
    
    currentY = 0; // Establecer posición home
    sprintf(outputBuffer, "Eje Y en posición home\r\n");
    sendUSBText(outputBuffer);
    

    CDC_TxQueue_Process();
    // Homing del eje Z
    sprintf(outputBuffer, "Homing eje Z...\r\n");
    sendUSBText(outputBuffer);CDC_TxQueue_Process();
    

    // Mover hacia el final de carrera Z (dirección negativa)
    HAL_GPIO_WritePin(GPIOA, Z_DIR_PIN, GPIO_PIN_SET); // Dirección negativa
    while (!isEndstopPressed('Z')) {
        Z_stepOnce();
        delay_us(STEP_DELAY_US/3);
    }
    
    // FASE 1: Retroceder 2mm del final de carrera Z
    HAL_GPIO_WritePin(GPIOA, Z_DIR_PIN, GPIO_PIN_RESET); // Dirección positiva
    for (int i = 0; i < 2*STEPS_PER_MM_Z; i++) { // Exactamente 2mm
        Z_stepOnce();
        delay_us(STEP_DELAY_US/3);
    }
    
    // Verificar que se liberó el switch después de alejarse 2mm
    if (isEndstopPressed('Z')) {
        sprintf(outputBuffer, "Error: Fin de carrera Z no se liberó después de alejarse 2mm\r\n");
        sendUSBText(outputBuffer);
        
        return;
    }
    
    
    
    // FASE 2: Regresar 2mm hacia el final de carrera Z
    HAL_GPIO_WritePin(GPIOA, Z_DIR_PIN, GPIO_PIN_SET); // Dirección negativa
    for (int i = 0; i < 2*STEPS_PER_MM_Z; i++) { // Exactamente 2mm de regreso
        Z_stepOnce();
        delay_us(STEP_DELAY_US); // Movimiento lento para precisión
    }
    // Pausa para estabilización
    HAL_Delay(100);
    // Verificar que el final de carrera esté presionado después de regresar 2mm
    if (!isEndstopPressed('Z')) {
        sprintf(outputBuffer, "Error: Fin de carrera Z no está presionado después de regresar 2mm\r\n");
        sendUSBText(outputBuffer);
        
        return;
    }
    
    currentZ = 0; // Establecer posición home
    sprintf(outputBuffer, "Eje Z en posición home\r\n");
    sendUSBText(outputBuffer);CDC_TxQueue_Process();
    

    // Mensaje final
    sprintf(outputBuffer, "Homing completado. Todos los ejes en posición home.\r\n");
    sendUSBText(outputBuffer);
    

    CDC_TxQueue_Process();

    // Rehabilitar interrupciones
    HAL_NVIC_EnableIRQ(EXTI15_10_IRQn);
}

// ========================================================================
// FUNCIONES PARA MANEJO DE PROGRAMA G-CODE
// =============================================================================

/**
  * @brief  Inicia el modo de almacenamiento de programa
  * @retval None
  */
void startProgramStorage(void) {
    isStoringProgram = true;
    programLineCount = 0;
    isProgramLoaded = false;
    
    // Limpiar buffer de programa
    for (int i = 0; i < MAX_GCODE_LINES; i++) {
        memset(gcodeProgram[i], 0, MAX_LINE_LENGTH);
    }
    
    sendUSBText("Modo almacenamiento activado. Envie comandos G-code.\r\n");
    sendUSBText("Termine con 'FIN' o 'PROGRAM_STOP'\r\n");
    //sendUSBText("ok\r\n");
}

/**
  * @brief  Detiene el modo de almacenamiento de programa
  * @retval None
  */
void stopProgramStorage(void) {
    isStoringProgram = false;
    
    if (programLineCount > 0) {
        isProgramLoaded = true;
        sprintf(outputBuffer, "Programa cargado: %d lineas almacenadas\r\n", programLineCount);
        sendUSBText(outputBuffer);
        
        sendUSBText("Use 'PROGRAM_RUN' para ejecutar o 'PROGRAM_INFO' para ver detalles\r\n");
    } else {
        sendUSBText("No se almacenaron lineas\r\n");
    }
    
    sendUSBText("ok\r\n");
}
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

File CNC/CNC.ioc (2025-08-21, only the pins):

Mcu.UserName=STM32F103C8Tx
PA10.Signal=GPIO_Output
PA11.Signal=USB_DM
PA12.Signal=USB_DP
PA13.Signal=SYS_JTMS-SWDIO
PA14.Signal=SYS_JTCK-SWCLK
PA2.Signal=USART2_TX
PA3.Signal=USART2_RX
PA8.Signal=GPIO_Output
PA9.Signal=GPIO_Output
PB0.Signal=GPIO_Output
PB1.Signal=GPIO_Output
PB12.Signal=GPXTI12
PB13.Signal=GPXTI13
PB14.Signal=GPXTI14
PB3.Signal=GPIO_Output
PB4.Signal=GPIO_Output
PB6.Signal=GPIO_Output
PB7.Signal=GPIO_Output
PB8.Signal=GPIO_Output
PB9.Signal=GPIO_Output
PD0-OSC_IN.Signal=RCC_OSC_IN
PD1-OSC_OUT.Signal=RCC_OSC_OUT

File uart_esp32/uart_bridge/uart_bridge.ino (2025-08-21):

/*
 * ESP32 UART Bridge para CNC Monitor
 * Actúa como puente entre STM32 (CNC) y PC vía WiFi/Serial
 * 
 * Conexiones físicas requeridas:
 * ESP32 GPIO16 (RX2) -> STM32F103 PA2 (USART2_TX)
 * ESP32 GPIO17 (TX2) -> STM32F103 PA3 (USART2_RX)
 * ESP32 GND         -> STM32F103 GND (IMPORTANTE!)
 * 
 * Configuración UART: 115200 baud, 8N1
 * 
 * Autor: Bridge para proyecto CNC
 * Fecha: Agosto 2025
 */

#include <WiFi.h>
#include <WebServer.h>
#include <WebSocketsServer.h>

// Configuración WiFi - CAMBIA ESTOS VALORES
const char* ssid = "BRUNO-WIN";
const char* password = "pirum11111";

// Configuración UART para comunicación con STM32
#define STM32_UART_BAUD 115200
#define STM32_RX_PIN 16  // GPIO16 -> conectar a STM32F103 PA2 (USART2_TX)
#define STM32_TX_PIN 17  // GPIO17 -> conectar a STM32F103 PA3 (USART2_RX)

// Servidores
WebServer server(80);
WebSocketsServer webSocket(81);

// Buffers para datos
String serialBuffer = "";
bool clientConnected = false;

void setup() {
  // Inicializar UART0 (debug/monitor)
  Serial.begin(115200);
  
  // Inicializar UART2 para comunicación con STM32
  Serial2.begin(STM32_UART_BAUD, SERIAL_8N1, STM32_RX_PIN, STM32_TX_PIN);
  
  delay(1000);
  Serial.println("\n=== ESP32 CNC UART Bridge ===");
  Serial.println("UART2 Config:");
  Serial.print("- Baud: ");
  Serial.println(STM32_UART_BAUD);
  Serial.print("- RX Pin (ESP32): ");
  Serial.print(STM32_RX_PIN);
  Serial.println(" -> conectar a STM32 PA2 (TX)");
  Serial.print("- TX Pin (ESP32): ");
  Serial.print(STM32_TX_PIN);
  Serial.println(" -> conectar a STM32 PA3 (RX)");
  
  // Configurar WiFi
  setupWiFi();
  
  // Configurar servidor web
  setupWebServer();
  
  // Configurar WebSocket
  webSocket.begin();
  webSocket.onEvent(webSocketEvent);
  
  Serial.println("Sistema listo!");
  Serial.print("IP Address: ");
  Serial.println(WiFi.localIP());
  Serial.println("Puerto WebSocket: 81");
  Serial.println("Conecta tu navegador a: http://" + WiFi.localIP().toString());
}

void loop() {
  // Manejar conexiones
  server.handleClient();
  webSocket.loop();
  
  // Leer datos del STM32 y enviar por WebSocket
  readFromSTM32();
  
  // Pequeña pausa para no saturar
  delay(10);
}

void setupWiFi() {
  WiFi.begin(ssid, password);
  Serial.print("Conectando a WiFi");
  
  while (WiFi.status() != WL_CONNECTED) {
    delay(500);
    Serial.print(".");
  }
  
  Serial.println();
  Serial.println("WiFi conectado!");
  Serial.print("IP: ");
  Serial.println(WiFi.localIP());
}

void setupWebServer() {
  // Página principal
  server.on("/", HTTP_GET, []() {
    server.send(200, "text/html", getWebPage());
  });
  
  // API para enviar comandos
  server.on("/send", HTTP_POST, []() {
    if (server.hasArg("command")) {
      String command = server.arg("command");
      sendToSTM32(command);
      server.send(200, "text/plain", "Comando enviado: " + command);
    } else {
      server.send(400, "text/plain", "Error: falta parámetro 'command'");
    }
  });
  
  // Estado del sistema
  server.on("/status", HTTP_GET, []() {
    String status = "{\n";
    status += "  \"wifi_connected\": " + String(WiFi.status() == WL_CONNECTED ? "true" : "false") + ",\n";
    status += "  \"client_connected\": " + String(clientConnected ? "true" : "false") + ",\n";
    status += "  \"ip_address\": \"" + WiFi.localIP().toString() + "\",\n";
    status += "  \"uart_baud\": " + String(STM32_UART_BAUD) + "\n";
    status += "}";
    server.send(200, "application/json", status);
  });
  
  server.begin();
  Serial.println("Servidor web iniciado en puerto 80");
}

void webSocketEvent(uint8_t num, WStype_t type, uint8_t * payload, size_t length) {
  switch(type) {
    case WStype_DISCONNECTED:
      Serial.printf("Cliente [%u] desconectado\n", num);
      clientConnected = false;
      break;
      
    case WStype_CONNECTED:
      {
        IPAddress ip = webSocket.remoteIP(num);
        Serial.printf("Cliente [%u] conectado desde %d.%d.%d.%d\n", 
                     num, ip[0], ip[1], ip[2], ip[3]);
        clientConnected = true;
        
        // Enviar mensaje de bienvenida
        webSocket.sendTXT(num, "ESP32 CNC Monitor conectado\n");
      }
      break;
      
    case WStype_TEXT:
      {
        String command = String((char*)payload);
        command.trim();
        Serial.printf("Comando recibido: %s\n", command.c_str());
        sendToSTM32(command);
      }
      break;
      
    default:
      break;
  }
}

void readFromSTM32() {
  while (Serial2.available()) {
    char c = Serial2.read();
    
    // Debug: mostrar byte recibido en hexadecimal también
    Serial.print(c);
    Serial.print(" [0x");
    Serial.print((uint8_t)c, HEX);
    Serial.print("] ");
    
    // Enviar por WebSocket si hay clientes conectados
    if (clientConnected) {
      String data = String(c);
      webSocket.broadcastTXT(data);
    }
  }
  
  // Debug: cada 5 segundos, verificar si hay datos pendientes
  static unsigned long lastCheck = 0;
  if (millis() - lastCheck > 5000) {
    lastCheck = millis();
    Serial.println("\n[DEBUG] Checking UART2 status...");
    Serial.print("Available bytes: ");
    Serial.println(Serial2.available());
  }
}

void sendToSTM32(String command) {
  // Asegurar que termine con \n
  if (!command.endsWith("\n")) {
    command += "\n";
  }
  
  // Enviar al STM32
  Serial2.print(command);
  
  // Log local
  Serial.print("-> STM32: ");
  Serial.print(command);
  
  // Confirmar por WebSocket
  if (clientConnected) {
    webSocket.broadcastTXT("SENT: " + command);
  }
}
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

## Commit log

2025-07-25 debugueamos como unos crackssss
    [CNC Debug.cfg]
2025-07-26 Homing precario andando
2025-07-26 movimiento en mm creo
    [soporte eje x.stl]
2025-07-26 commit antes del desastre o la coronación de gloria
    [alarm_codes_en_US.csv, build_option_codes_en_US.csv, error_codes_en_US.csv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]
2025-07-27 listo con el gcode python
2025-07-28 antes de tocar settings
2025-07-29 se esta borrando el gcode programado en la optimización
2025-08-05 que dios nos ayude a entender el planner
2025-08-07 Planer con velocidad chota
2025-08-07 ANDA, LOS PRINT MA O MENO
2025-08-11 print un poco más limpios
2025-08-11 homing check
2025-08-11 un poco de limpieza
2025-08-12 La velocidad anda como la nalga
2025-08-13 velocidad check
2025-08-21 posición actualizada en tiempo real
    [fin_de_carrera_eje_x.stl, fin_de_carrera_eje_y.stl, fin_de_carrera_eje_z.stl]

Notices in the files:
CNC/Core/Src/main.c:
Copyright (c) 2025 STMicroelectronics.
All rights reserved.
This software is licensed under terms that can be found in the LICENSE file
